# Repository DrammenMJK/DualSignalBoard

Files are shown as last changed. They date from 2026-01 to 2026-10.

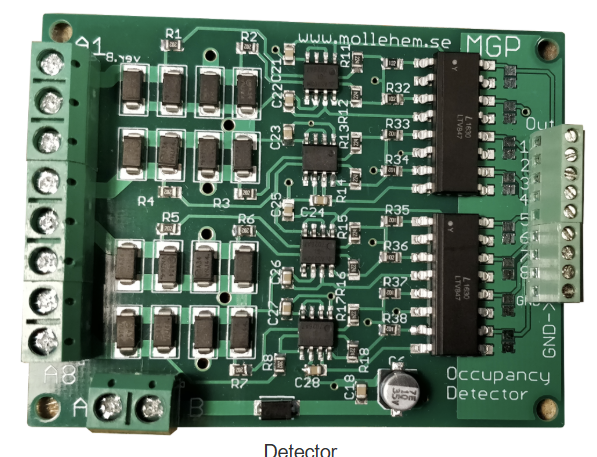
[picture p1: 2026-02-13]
MollhemSporavkanningDiodex8.png

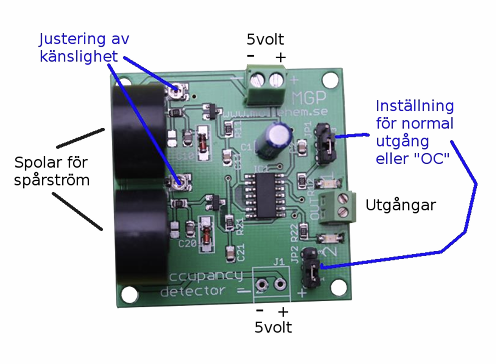
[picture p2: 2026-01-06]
MollehemSporavkanningx2.png

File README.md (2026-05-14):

# Railroad Signal Controller – Design Specification

## State Transitions and Signal Behavior

This section describes how the controller transitions between states based on
inputs and events.

---

### Direction State

**Direction** defines which end of the block is permitted to show green.

| Direction | Meaning |
|---|---|
| **A → B** | **Signal A** is the active green end |
| **B → A** | **Signal B** is the active green end |
| **None**  | **Signal A** and **Signal B** is both Red |

Direction **None** is the default state.

---

### Input Types

| Input | Trigger Type | Active State |
|---|---|---|
| PBA | **Edge-triggered** | LOW (press) |
| PBB | **Edge-triggered** | LOW (press) |
| SCA | **Level-based** | LOW (Closed) |
| SCB | **Level-based** | LOW (Closed) |
| SCC | **Level-based** | LOW (Closed) |
| Train | **Level-based** | HIGH (Train present) |

**Note:** The Train input is active HIGH (unlike other inputs which are active LOW). The train detection includes:
1. **IIR filter with hysteresis (20ms window)** - A leaky integrator filters the raw signal. Schmitt trigger thresholds prevent oscillation:
   - Goes HIGH when accumulator exceeds 60% (12ms)
   - Goes LOW when accumulator drops below 40% (8ms)
   - This ignores brief glitches and noisy signals like `0 1 0 1 0 1`
2. **2-second delay** - After the filtered signal goes HIGH, there is an additional 2-second delay before the signals are forced to red. If the filtered signal goes LOW before 2 seconds, the timer resets.

---

### Direction State Transitions

Direction changes **only on button press edges** and only when **no train is present**, and only if the  direction is not "None".

The possible directions are:

**A → B**
**B → A**
**None**

| Current Direction | Train present | Button event | Next Direction |
| --- | --- | --- | --- |
| None | No | **PBA pressed** | **A → B** |
| None | No | **PBB pressed** | **B → A** |
| Any | No | PBA or PBB pressed | No change |
| Any | Yes | PBA or PBB pressed| No change (stays None) |

Notes:

- PBA and PBB are evaluated on the **press edge only**
- Holding a button does **not** retrigger
- Pressing the button corresponding to the current Direction has no effect

Switches affects the direction signals

If any switch changes, then Direction is None thereafter. It does NOT change back.

---

### Signal Output Logic (Normal Operation)

| Condition | Signal A – Red | Signal A – Green 1 | Signal A – Green 2 | Signal B – Red | Signal B – Green 1 | Signal B – Green 2 |
|---|---|---|---|---|---|---|
| Direction **None** (or Train present) | ON | OFF | OFF | ON | OFF | OFF |
| Direction **A → B**, SCB open | ON | OFF | OFF | ON | OFF | OFF |
| Direction **A → B**, SCB closed, SCA open | OFF | ON | OFF | ON | OFF | OFF |
| Direction **A → B**, SCB closed, SCA closed | OFF | ON | ON | ON | OFF | OFF |
| Direction **B → A**, SCB open | ON | OFF | OFF | ON | OFF | OFF |
| Direction **B → A**, SCB closed, SCC or SCD open | ON | OFF | OFF | OFF | ON | OFF |
| Direction **B → A**, SCB closed, SCC closed, SCD closed | ON | OFF | OFF | OFF | ON | ON |

---

### Debug Mode State Transitions

| Current Debug Mode | Debug button pressed | Next Debug Mode |
|---|---|---|
| Off | Yes | AllOn |
| AllOn | Yes | Auto |
| Auto | Yes | Manual |
| Manual (step < last) | Yes | Manual (next step) |
| Manual (last step) | Yes | Off |

---

### Debug Cancellation

| Event | Effect |
|---|---|
| PBA or PBB pressed while in debug | Debug mode exits immediately |
| Debug cancelled | Direction does **not** change on same press |

---

### Power-On / Reset State

| Condition at Power-On | Resulting State |
|---|---|
| Debug button not held | Direction restored from EEPROM |
| Debug button held | Direction forced to **None**, EEPROM reset |

---

### Summary Rules

- Direction is **explicitly set**, never toggled
- PBA always selects **A → B**
- PBB always selects **B → A**
- Pushbuttons are **edge-triggered - high -> low**
- Switches and Train detection are **level-based**
- Train presence overrides all other logic
- Debug modes override lamp outputs but **do not modify Direction**
- EEPROM reset always restores a **known, safe Direction**

---

## Controller

- Board: **Arduino Uno–compatible (GeekCreit)**
- MCU: **ATmega328P**
- Clock: **16 MHz**
- EEPROM: **1 KB (on-chip)**

---

## Power

- System supply: **+10–12 V**
- Logic supply: **Buck regulator → 5.0–5.1 V**
- Arduino powered via **5V pin**
- VIN not used
- Grounds common for logic and outputs

---

## Inputs (All via Optocouplers)

- Optocoupler: **PC817 / EL817**
- Input voltage: **10–12 V**
- LED series resistor: **3.3 kΩ**
- Typical LED current: **~2–3 mA**
- Arduino side: `INPUT_PULLUP`
- Logic level: **LOW = active** (except Train input which is **HIGH = active**)

### Input Functions and Pins

| Function | Arduino Pin | Board Label |
|---|---|---|
| Train detect | D2 | 2 |
| Pushbutton A | D3 | 3 |
| Pushbutton B | D4 | 4 |
| Switch A closed | D5 | 5 |
| Switch B closed | A2 | A2 |
| Switch C closed | D6 | 6 |
| Switch D closed | A3 | A3 |
| Debug button | A4 | A4 |
| Serial enable jumper | A5 | A5 |

---

## Outputs (Discrete Transistor Drivers)

- Topology: **NPN low-side switching**
- Transistor: **BC547 / BC337 / 2N2222**
- Base resistor: **4.7 kΩ**
- Base pull-down: **100 kΩ (base → emitter)**
- Load: **Signal LEDs**
- LED supply: **+10 V**
- LED current: **10 mA**

### LED Series Resistor

- Nominal value: **680 Ω**
- Acceptable range: **680–820 Ω**
- Power rating: **¼ W**

### Output Functions and Pins

| Signal | Arduino Pin | Board Label |
|---|---|---|
| Signal A – Red | D7 | 7 |
| Signal A – Green 1 | D9 | 9 |
| Signal A – Green 2 | D8 | 8 |
| Signal B – Red | D10 | 10 |
| Signal B – Green 1 | D12 | 12 |
| Signal B – Green 2 | D11 | 11 |

- Logic: **Arduino HIGH = LED ON**
- Hardware inversion handled by transistor

---

## Debug LEDs (5 V Logic)

- Active-high
- Direct drive from Arduino pin
- Resistor: **1 kΩ**
- LED current: **~3 mA**

---

## Debug Button Behavior

- Button connected to **A4 → GND**
- `INPUT_PULLUP`
- Active-low

### Debug State Sequence

1. ALL_ON (=1) **All signal LEDs ON**
2. CYCLE (=2) **Automatic cycle** (1 s per LED):  
   A_G1 → A_G2 → A_R → B_G1 → B_G2 → B_R
3. MAN_0 (=3), MAN_1 (=4) ... MAN_5 (=8) **Manual step** (one press per LED, same order)
4. OFF (=0) (When enter state, Flash all 3 times, 0.5 sec between, then exit debug) **Exit debug → normal operation**

- Any press of **signal button A or B**:
  - Cancels debug immediately
  - Does **not** toggle signal state on same press

---

## Normal Signal Logic

- Default Direction is None
  Both signals are Red
- Startup state:
  - Direction None
- Train present (after 2-second delay):
  - Direction None
- Pushbutton A or B:
  - Sets direction only if Direction is None
  - Ignored if train present
- Switch A closed :
  - Both Greens for A on.  
- Switch B and C closed:
  - Both Greens for B is on.

- When a Train is present for 2 continuous seconds, both signals go Red.
- When train is no longer present, signals stay Red (direction remains None).

---

### Reset Mechanism

- Reset is performed using **power cycling**
- No dedicated reset jumper required

### Reset Steps

1. Power **OFF** the board using **JP2**
2. **Press and hold** the **Debug button (A4)**
3. Power **ON**
4. Release the Debug button after startup

### Reset Effect

- `g_stateQ` is forced to **false**
- Signal **A** becomes the active green end
- EEPROM address `0` is updated accordingly

---

## Serial Debug Output

- Baud rate: **115200**
- Status printed once per second
- Controlled by jumper on **A5**
  - Jumper installed (LOW): Serial enabled
  - Jumper removed (HIGH): Serial disabled

---

## Wiring Notes

- Input wire lengths: **2–5 m**
- Optocouplers required on all inputs
- Optional: **100 nF capacitor** across opto LED for noisy runs
- Avoid using pins **D0/D1**
- Pin **D13** unused (on-board LED available)

---

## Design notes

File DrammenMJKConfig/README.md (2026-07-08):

# DrammenMJKConfig

Console tool for configuring the LysKontroll Arduino controller over a serial connection.
Run it on a PC connected to the Arduino via USB. The program stores all configuration
in the Arduino's EEPROM and does not need to run during normal layout operation.

---

## Requirements

- .NET 8 runtime
- Arduino connected via USB (CH340 or genuine USB)
- Baud rate: 115200

---

## Starting the program

```txt
DrammenMJKConfig.exe
```

or

```txt
dotnet run
```

The program lists available COM ports. If only one is present it connects automatically;
otherwise you are prompted to choose. After connecting it waits 2 seconds for the Arduino
to finish its reset, then shows the main menu.

```txt
D = Debug mode    C = Config mode    V = Verify    Q = Quit
```

---

## Debug mode (D)

Used to check LED wiring before configuration.

| Key | Action |
|-----|---|
| A | Toggle all LEDs on / off — reveals short circuits |
| L | Cycle all LEDs one at a time, 1 second each (any key to stop) |
| Q | Exit debug mode |

---

## Config mode (C)

Stores hardware mappings in EEPROM. Run each command once during initial setup,
or again whenever the hardware changes.

**Recommended first-time order:** 1 → 2 → 3 → M → D → 4

### Command 1 — Motor scan

Discovers all switch motors in a single scan. Each motor pair is driven in turn:
- **Feedback changes** → Pens motor — operator confirms and sets Rett/Avvik polarity.
- **Timeout, no feedback change** → Dreieskive — operator confirms and sets CW/CCW polarity.

| Key | Action |
|-----|---|
| Y | Confirm / correct detection |
| N | Skip to next motor |
| R | Pens is currently at Rett position |
| A | Pens is currently at Avvik position |
| 1 | The `01` bit pattern drives CW (Dreieskive polarity) |
| 2 | The `10` bit pattern drives CW (Dreieskive polarity) |
| X | Emergency stop all motors |
| Q | Done, return to config menu |

### Command 2 — Manual switch → Pens mapping

Links each physical panel switch (B–I) to the corresponding Pens motor and feedback inputs.

1. Move **all** panel switches to Rett before starting.
2. Select a Pens letter (B–I).
3. Flip its panel switch to Avvik and back; the Arduino detects which input changed.
4. Confirm or retry, then set polarity.

| Key | Action |
|-----|---|
| B–I | Select a Pens to configure |
| Y | Confirm detected switch |
| N | Retry |
| R | Set polarity: this position is Rett |
| A | Set polarity: this position is Avvik |
| Q | Done |

### Command 3 — LED mapping

Maps each Pens (B–I) to its physical Rett and Avvik indicator LEDs on the panel.
All Penser should be at Rett before starting (run Command 2 first).

| Key | Action |
|-----|---|
| B–I | Select Pens to configure |
| N | Next LED |
| P | Previous LED |
| S | Save this LED for current switch position (Rett first, then Avvik) |
| Q | Done |

### Command M — Moment button

Detects which input pin the physical moment signal button is connected to.
Press the button when prompted. Confirm with Y or retry with N.

### Command D — Dreieskive switch

Configures the three-position turntable switch (middle / CW / CCW).

1. Move the switch to the **middle** position and press Enter.
2. Move to **CW** when prompted.
3. Move back to middle, then to **CCW**.
4. Confirm each step with Y.

### Command 4 — LED routing matrix

Controls which switch conditions must be satisfied before each indicator LED lights.
Configuration is loaded from a site-specific JSON file and uploaded to EEPROM.
See [RoutingMatrix.md](RoutingMatrix.md) for the file format and a complete Fossli example.

```
Routing> L   Load JSON file and upload to Arduino
Routing> S   Download current matrix from Arduino and save to JSON file
Routing> ?   Show JSON file format and example
Routing> Q   Done
```

When loading, the program:
1. Prompts for the path to a `.json` file (any name, one per site).
2. Displays the `site` label from the file so you can confirm it is the right one.
3. Validates all conditions and reports every error before asking to upload.
4. Sends the matrix to Arduino and confirms each LED row is accepted.

### Command R — Reset

**Destructive.** Erases all configuration from EEPROM (motor mappings, switch mappings,
LED mappings, polarity, routing matrix). The layout signal direction state is not affected.
Requires typing Y to confirm.

After a reset, run Commands 1, 2, 3, M, D and 4 to reconfigure.

---

## Verify mode (V)

Checks that the hardware still works correctly using the stored configuration.
Nothing is written to EEPROM.

### Command 1 — Motors and Pens feedback

For each configured Pens the Arduino:
1. Reads current position from feedback switches.
2. Moves the motor to the opposite position and confirms feedback changes.
3. Moves back and confirms again.
4. Reports PASS or FAIL.

The Dreieskive motor is skipped (no feedback switches).

| Key | Action |
|-----|---|
| X | Emergency stop all motors |
| Q | Abort and return to verify menu |

---

## Site-specific files

The LED routing matrix is the only configuration stored outside the Arduino.
Keep one JSON file per physical layout:

| Site | File |
|---|---|
| Fossli | `Fossli.json` |
| Other site | `Sentrum.json`, etc. |

Pass the full path when prompted by Command 4 → L. The file may be stored anywhere.
See [RoutingMatrix.md](RoutingMatrix.md) for the format specification.

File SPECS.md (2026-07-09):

# LysKontroll — System Specification

Model railway layout controller for Drammen MJK, station Fossli.
Hardware: Arduino Uno (ATmega328P). Software: Arduino firmware + C# config tool.

---

## Hardware

| Component | Description |
|---|---|
| ATmega328P | 32 KB flash, 2 KB SRAM, 1 KB EEPROM (100 K write cycles) |
| MCP23017 | I2C GPIO expanders for additional I/O |
| Pens motors | Turnout motors, stall-hold (`01` or `10`), never `00` |
| Feedback switches | Two per Pens (Rett + Avvik pin), read via I2C |
| Manual switches | One per Pens (operator panel), read via I2C |
| Dreieskive motor | Rotating platform, 3 states: `00`=stopped, CW, CCW |
| Dreieskive switch | 3-position panel switch: middle / CW / CCW |
| LEDs | Rett + Avvik indicator per Pens, driven via I2C |
| Moment button | Physical signal-operation button |

---

## Site Configuration

Stored in EEPROM and in the site JSON file. Change per site without recompiling
(simulator uses `#define`; real firmware reads from EEPROM after initial upload).

| Parameter | Default | Fossli |
|---|---|---|
| `FIRST_PENS` | `'A'` | `'B'` |
| `LAST_PENS` | site-specific | `'I'` |
| `MAX_PENS` | 26 (A–Z) | 26 |
| `NUM_LED_OUTPUTS` | site-specific | 16 |

`LED_COUNT` (number of logical LED slots in the routing matrix) is derived: `(LAST_PENS - FIRST_PENS + 1) * 2`. It is **not** a site config — it follows automatically from the Pens range. `NUM_LED_OUTPUTS` is the number of physical hardware LED driver outputs and must be set per site.

---

## EEPROM Layout (1 024 bytes, ATmega328P)

All slots initialised to `0xFF`. `0xFF` in any slot = not yet configured.
Regions are indexed from `FIRST_PENS` (index 0 = `FIRST_PENS`, 1 = next letter, …).

| Address | Size | Content |
|---|---|---|
| `0x01` | 1 | Magic byte (`0xA5` = EEPROM has been initialised) |
| `0x0A` | 1 | Dreieskive last known position (display hint only) |
| `0x10` (REGION1_BASE) | MAX_PENS | Motor pair index per Pens |
| `0x30` (REGION1_POL) | MAX_PENS | Motor polarity (position at scan time: 0=Rett, 1=Avvik) |
| `0x50` (REGION2_RETT) | MAX_PENS | Feedback Rett pin per Pens |
| `0x70` (REGION2_AVVIK) | MAX_PENS | Feedback Avvik pin per Pens |
| `0x90` (REGION3_BASE) | MAX_PENS | Manual switch pin per Pens |
| `0xB0` (REGION4_RETT) | MAX_PENS | Rett LED index per Pens (`0xFF`=not set, `0xFE`=no LED, `0x00–0x0F`=index) |
| `0xD0` (REGION4_AVVIK) | MAX_PENS | Avvik LED index per Pens (same encoding) |
| `0xF0` (REGION5_MOTOR_PIN) | 1 | Dreieskive motor pair index |
| `0xF1` (REGION5_MOTOR_POL) | 1 | Dreieskive CW polarity (0=`01`, 1=`10`) |
| `0xF2` (REGION5_SW_CW) | 1 | Dreieskive switch CW pin |
| `0xF3` (REGION5_SW_CCW) | 1 | Dreieskive switch CCW pin |
| `0xF4` (REGION5_MOMENT) | 1 | Moment button pin |
| `0x100` (REGION6_BASE) | 144 | LED routing matrix (16 LEDs × 9 bytes) |

Pens positions are NOT stored in EEPROM — kept in RAM, refreshed from I2C feedback
on every loop iteration. EEPROM write cycles are preserved.

---

## Serial Protocol

Baud rate: **115 200**.

### C# → Arduino
- Single ASCII characters (no newline) for interactive commands and key presses.
- Full lines ending `\n` only during routing matrix upload.

### Arduino → C#
- Lines ending `\r\n`.
- **`!` prefix** — status message: always displayed immediately, `!` stripped.
- **No prefix** — protocol response (`READY`, `OK`, `STORED`, `END`, `ERR`):
  queued in capture mode, or displayed with `[A]` prefix in relay mode.

### C# ReadLoop (background thread)
```
line starts with '!'  →  Console.WriteLine(line without '!')
capturing             →  enqueue for caller (GetCapturedLine)
otherwise             →  Console.WriteLine("[A] " + line)
```

### Capture mode
Used for structured exchanges (routing matrix upload/download).
`StartCapture()` redirects non-`!` lines to a queue.
`StopCapture()` resumes normal relay behaviour.

---

## C# Program Structure

```
Program.cs          — port selection, startup, main menu (C / D / V / Q)
ArduinoConnection   — serial port + ReadLoop thread
ConfigSession       — config mode commands
DebugSession        — debug mode
VerifySession       — verify mode
```

After connecting, `Program.cs` waits 2 s then sends `'S'` and waits 400 ms
to let the Arduino return EEPROM status before showing the main menu.

---

## Relay Mode

`Relay()` in `ConfigSession` forwards every keystroke to the Arduino and
displays `!` status lines. C# has no command knowledge in relay mode — the
Arduino drives the entire interaction.

- **ESC** — breaks `Relay()` on the C# side AND is sent to the Arduino so
  the current command can also abort. Both sides exit simultaneously.
- Commands that complete **naturally** (not via ESC) must call
  `while (waitKey() != ESC) {}` before returning, so `Relay()` also exits.

---

## Key Bindings

### Main menu (`Program.cs`)
| Key | Action |
|-----|---|
| C | Config mode |
| D | Debug mode |
| V | Verify mode |
| Q | Quit (sends Q to Arduino for reset, then C# exits) |

### Config menu (Arduino `runConfig`, C# `ConfigSession`)
| Key | Action |
|-----|---|
| 1 | Motor scan |
| 2 | Switch mapping |
| 3 | LED mapping |
| 4 | Routing matrix |
| M | Moment button |
| D | Dreieskive switch |
| R | Reset EEPROM |
| Q | Exit config mode |

### Motor scan (relay mode)
| Key | Action |
|-----|---|
| `FIRST_PENS`–`LAST_PENS` | Identify which Pens just moved |
| `0` | Skip this pair |
| `R` / `A` | Pens is now at Rett / Avvik |
| `1` / `2` | Dreieskive CW = `01` / `10` pattern |
| `X` | Emergency stop |
| `Y` / `N` | Override duplicate / re-enter letter |
| Esc | Abort scan |

### Switch mapping (relay mode)
| Key | Action |
|-----|---|
| `FIRST_PENS`–`LAST_PENS` | Map or re-map that Pens switch |
| Esc | Finish |

### LED mapping (relay mode)
| Key | Action |
|-----|---|
| `FIRST_PENS`–`LAST_PENS` | Select Pens to configure (or re-configure) |
| `N` / `P` | Next / previous LED index (wraps) |
| `S` | Save current LED for this position (Rett first, then Avvik) |
| `0` | No physical LED for this position (stores `LED_NO_PIN = 0xFE`) |
| Esc | Finish |

### Routing matrix (structured protocol, not relay)
| Key | Action |
|-----|---|
| `U` | Upload from C# JSON file |
| `D` | Download to C# JSON file |
| `?` | Show JSON format |
| Esc | Done |

---

## Motor Scan Flow

1. Pre-populate `assigned[]` and `pairDone[]` from EEPROM.
2. If **all** Pens and Dreieskive are already configured:
   - Prompt "Type a Pens letter to re-configure it, or Esc to finish."
   - Operator types a letter (e.g. `C`): clears that one Pens from session state and clears its pair from `pairDone[]`.
   - Falls through to the pair scan — only the cleared pair will run; all others skip.
   - After the pair is re-assigned, loops back to step 2 to offer editing another.
   - `Esc` at this prompt → "Motor scan done." and returns.
3. Loop pairs `0..8`:
   - `pairDone[pair]` → silent skip.
   - All Pens already assigned → silent skip (only Dreieskive pair can still fire).
   - **Dreieskive pair** (no feedback timeout): automatically identified — ask `1`/`2` for CW polarity.
   - **Pens pair** (feedback detected): show remaining unassigned letters, operator types letter.
     - Duplicate detected → `Y` override / `N` re-enter.
     - Ask current position `R`/`A`, store to EEPROM.
4. Early exit when all Pens **and** Dreieskive are done.
5. `"Motor scan complete. Press Esc to return."` — waits for Esc.

---

## Switch Mapping Flow

Loop: operator types any Pens letter to map or re-map it, Esc to finish.
1. Check motor configured for that Pens (REGION1_BASE); error if not.
2. Drive that Pens to Rett (so switch follows).
3. Prompt operator to flip the panel switch to Avvik then back to Rett.
4. Detect switch (2 s), store pin to EEPROM, confirm stored.

No Y/N confirmation needed — the operator typed the letter intentionally.
Already-mapped Pens are silently re-mapped when the letter is typed again.

---

## LED Routing Matrix

- 16 logical LEDs: `B_Rett`, `B_Avvik`, `C_Rett`, `C_Avvik` … `I_Rett`, `I_Avvik`.
- Each LED holds up to 4 conditions (OR of AND-chains).
- Each condition: `rettMask` + `avvikMask` (bitmask of Pens that must be in that position).
- `count = 0xFF` → default 1-to-1 (LED lights when its own Pens is in matching position).
- `count = 0x00` → suppressed (always off; used for shared physical LEDs).
- Loaded from a site-specific JSON file (e.g. `Fossli.json`).

Wire format per LED: `CC [RR AA …]` (hex, space-separated).

---

## Simulator (`Simulator.ino`)

Replaces real hardware for testing the C# config program on an empty Arduino Uno.

- All strings in flash via `F()` and `vsnprintf_P`. No `String` objects.
- `#define ESC '\x1B'` — abort/quit inside all commands.
- `Q` reserved for top-level menus only (`runConfig`, `loop`).
- `'S'` command (silent) — returns EEPROM status; sent by C# after connect.
- `softReset()` — watchdog reset; **does not clear EEPROM**.
- `SIM_DREIESKIVE_PAIR = 4` — pair with no feedback (simulated Dreieskive).
- `SIM_PENS_COUNT = 8` — Fossli has 8 Pens (B–I).
- EEPROM indexing: `eepromIdx = k - FIRST_PENS` (site-relative, 0 = first Pens).
- In-session arrays (`assigned[]`, `simPensPos[]`): indexed by `k - 'A'` (universal, 0 = A).

---

## Key Design Rules

**Y, N, and all A–Z letters are reserved as Pens identifiers.**
They must NEVER be used as yes/no confirmation keys inside any command that
also accepts Pens letter input. Since FIRST_PENS/LAST_PENS may expand to cover
the full A–Z range on other sites, any A–Z letter is off-limits as a confirmation
key in relay mode.

Safe confirmation/action keys (outside A–Z or not reachable from Pens letter range):
- Digits: `0`–`9`
- Esc (`\x1B`)
- `1` / `2` (Dreieskive polarity choice)

Y/N are only permitted in pure C# dialogs that never reach the Arduino in relay mode
(e.g. "Upload to Arduino? Y/N" in `LoadAndUpload`), or in Arduino commands that do
not accept Pens letters at all (moment button, Dreieskive switch) — and only then on
sites where Y/N are outside FIRST_PENS..LAST_PENS.

**Prompts must appear before blocking on input.**
The Arduino must send its status prompt BEFORE calling `waitKey()`, so the user
sees what to type without needing to press a dummy key first. Invalid keys are
silently ignored (loop repeats the prompt).

---

## Conventions

| Term | Meaning |
|---|---|
| Rett | Straight-through position (value 0) |
| Avvik | Diverging position (value 1) |
| Pens | Physical turnout / switch (Norwegian: veksel) |
| Dreieskive | Rotating platform (turntable) |
| eepromIdx | `k - FIRST_PENS` — EEPROM array offset for Pens letter `k` |
| pensIdx | `k - 'A'` — universal in-memory index for Pens letter `k` |

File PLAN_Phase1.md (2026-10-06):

# Plan: Phase 1 Implementation (FSCB over direct I2C)

Implements the Phase 1 scope defined in `PlanExtended.md`. This document is the
concrete build plan: code layering, protocol, EEPROM layout and task order.

## Relationship to other docs

- `PlanExtended.md` is the source of truth for scope and hardware facts. This
  file only turns it into an implementation plan.
- `PlanExtended.md` describes a **new, bigger architecture** (SVB + SCB boards,
  numbered switches, 4 I2C buses via a mux) that supersedes the older
  letter-based Penser (A–Z) extension of the original DualSignal lamp
  controller described in `SPECS.md` / `PLAN_PensControl.md` / `PLAN_Refactor.md`.
- `Firmware_FirstAttempt/Firmware.ino` is an implementation of that **older**
  Pens-letter system (`MF`/`MS`/`FW`/`SW`/`SCA`, EEPROM Region1–6, Pens A–Z).
  Per `PlanExtended.md`: "we will not reuse this". It's still useful as a
  reference for MCP23017 driver code style and pin-encoding tricks, but the
  command protocol and EEPROM layout below are new and unrelated to Region1–6.
- `Simulator/Simulator.ino` is the copy source for `Firmware/`. We keep its
  **transport plumbing** (line reader, capture-mode-safe response format,
  `!`-prefixed status lines) and its **EEPROM primitive commands**
  (`PING`/`SI`/`ER`/`EW`/`EC`/`RST`), and discard the simulated-Pens business
  logic entirely.

## Guiding architectural decision (revised)

`PLAN_Refactor.md`'s "config logic lives in C#" rule applies to
**config-time, interactive** logic — scan loops, operator prompts, "which one
moved?" bookkeeping. It does **not** mean the PC is the runtime brain: in
production there is no PC attached. The Arduino (CB) must be able to power up
and run the layout entirely on its own, driven by:

- its own downloaded EEPROM config (built once, during config sessions), and
- hardware events on the buses — an SVB's panel switch changing state, later
  (Phase 2+) triggering the corresponding SCB motor, all inside the firmware.

So the split is:

| Lives in C# (`DrammenMJKConfig`) | Lives in firmware (`Firmware.ino`) |
|---|---|
| Editing `hardware.json` (board types × site board inventory) and `SystemConfig.json` | Applying the uploaded board hardware table (IODIR/GPPU per board) at boot and live on upload |
| Interactive discovery UX: motor scan prompts, "which switch moved?", Rett/Avvik confirmation | The switch table itself (slot → board + motor bit + polarity + feedback bits), read at runtime |
| Human-friendly naming: SVB name/number ↔ switch number ↔ switch slot | Resolving "drive switch N" / "read switch N" from that table, without needing a PC |
| Building/uploading both tables during config | — |
| — | (Later) reacting autonomously to SVB switch-change events, same table, same resolver |
| — | (Later) signal-lamp PWM/dimming logic, native firmware, not decomposed to C# — see [Signal lamp logic](#signal-lamp-logic-out-of-scope) |

Practically, this means the wire protocol has two tiers:

- **Raw discovery primitives** (`MDIR`/`MPU`/`MW`/`MR`/`MPOLL`/`MBIT`) — take
  an explicit `(vaddr, port, bit)` because during Motor Scan that mapping is
  exactly what's *unknown* and being discovered. These are config-time-only.
- **Switch-level commands** (`SW`/`SR`, new) — take only a switch **slot**
  number. No port, no bit, no vaddr. The firmware looks those up itself from
  the switch table already written into EEPROM by Motor Scan. This is what
  Command mode uses, and it's the same lookup the future autonomous runtime
  loop will use — so Command mode is effectively "manually trigger the same
  resolver the SVB-event loop will call later," not a separate code path.

---

## Virtual addressing

`PlanExtended.md`'s "System description" section gives the site's full address
map and states the formula as "Bus number * 20 + local address". The worked
table underneath it is the authoritative data, and it's consistent with a
multiplier of **`0x10`**, not `0x20`:

| Bus | Boards | Real address(es) | Virtual address(es) |
|---|---|---|---|
| 0 — Stillverk | SVB1 LedAndSwitchesFossli, SVB2 LedAndSwitchesHavna | `0x20`,`0x21`,`0x22`,`0x23` | same (`0x20`–`0x23`) |
| 1 — Havna/Vallekilen | Havna SCB, Vallekilen SCB, Vallekilen SVB | `0x20`,`0x21`,`0x22` | `0x30`,`0x31`,`0x32`,`0x33` |
| 2 — Fossli | Fossli Høyre (FSCB), Fossli Venstre | `0x20`,`0x21` | `0x40`,`0x41` |
| 3 — Sidespor | Sidespor | `0x20` | `0x50` |

(Vallekilen is two virtual addresses, `0x32` SCB + `0x33` SVB — not a single
combined board as an earlier draft of `PlanExtended.md` implied.)

Each real address diffs from its virtual address by exactly `bus * 0x10`
(Bus1: `+0x10`, Bus2: `+0x20`, Bus3: `+0x30`). So:

```
virtual_address = bus_number * 0x10 + real_i2c_address        // real_i2c_address is always 0x20–0x27 (MCP23017)

// decode (inverse), given real addresses are always in 0x20–0x2F:
bus_number      = (virtual_address >> 4) - 2
real_i2c_address = 0x20 | (virtual_address & 0x0F)
```

This holds for every entry in the table above, including Bus 0 where the
"virtual == real" statement falls out of the formula for free (`bus=0` adds
nothing). It also holds for FSCB itself: Phase 1's direct-wired address
`0x20` **is already a valid virtual address** for `bus=0` — so Phase 1 doesn't
need a special case, it's just the `bus=0` instance of the same scheme, and
the value doesn't change when FSCB is later moved to Bus 2 (`0x40`) — only the
`BoardConfig` entry's virtual address constant changes.

Bus handling lives in the firmware's I2C layer, and only there: the raw
discovery commands and the switch table both carry `vaddr`, never `bus`. The
resolver decodes `bus`/`real_addr` from `vaddr` and selects the mux channel
before issuing the transaction. Dispatch code never mentions `bus`.

**No board-discovery/scan command exists or is wanted.** Every board's
virtual address is a known, fixed constant from the site map above — it's
data in `BoardConfig`, not something firmware or the PC probes for. A board
that doesn't answer on its known address means its I2C link is broken or it
isn't wired in yet, not "not found".

---

## Firmware layering (`Firmware/Firmware.ino`)

```
┌──────────────────────────────────────────────────────────────────┐
│ 1. Serial transport (PSL)                                        │
│    readLine(), dispatch(), OK/ERR/status(!) conventions          │
│    — copied from Simulator.ino, simulation stripped              │
├──────────────────────────────────────────────────────────────────┤
│ 2. Command dispatch                                               │
│    PING / SI / ER / EW / EC / RST        (local, unchanged)       │
│    MDIR / MPU / MW / MR / MPOLL / MBIT   (raw, discovery-only)    │
│    SW / SR                                (switch-table, operational)│
│    HWU / HWD                              (board hw table, bulk) │
│    SCU / SCD                    (switch/SVB-switch/dreieskive/LED, bulk)│
├──────────────────────────────────────────────────────────────────┤
│ 3a. Board hardware table (EEPROM-backed — see EEPROM layout)      │
│    resolve_board_hw(vaddr) -> {iodirA, iodirB, gppuA, gppuB}      │
│    or NOT_CONFIGURED. Applied to every registered vaddr at boot,  │
│    and immediately (live) whenever HWU stores a new table.        │
│ 3b. Switch table (EEPROM-backed, generic schema)                  │
│    resolve_switch(slot) -> {motorVAddr, motorBit, polarity,       │
│      feedbackVAddr, fbRettBit, fbAvvikBit}  or NOT_CONFIGURED     │
│    motor/feedback vaddr independent — a 2-chip board's feedback   │
│    can land on the other chip from its motor.                     │
│    Used by SW/SR now; will be used by the autonomous SVB-event    │
│    loop later (Phase 2+) — same function, no protocol change.     │
├──────────────────────────────────────────────────────────────────┤
│ 4. Virtual-address resolver (bus lives here, and only there)      │
│    resolve_vaddr(vaddr) -> { bus, real_addr }                     │
│      bus       = (vaddr >> 4) - 2                                  │
│      real_addr = 0x20 | (vaddr & 0x0F)                             │
│    i2c_select_bus(bus)                                             │
│    Phase 1: bus is always 0 -> select is a no-op                  │
│              (no mux fitted; single direct bus)                    │
│    Phase 2+: drives the I2C mux channel select                      │
├──────────────────────────────────────────────────────────────────┤
│ 5. Generic MCP23017 driver                                        │
│    mcp_write_reg / mcp_read_reg / mcp_set_dir / mcp_set_pu        │
│    Same 3 primitives as PLAN_Refactor.md's "custom driver"        │
│    Reused unchanged by every future board type.                    │
└──────────────────────────────────────────────────────────────────┘
```

There is now **no compiled-in board-specific code at all**, not even the SCB
port template — layers 3a/3b are both generic table interpreters over
EEPROM data. That's an improvement on the previous draft, which still
hardcoded FSCB's port setup directly in firmware C++ (recompile+reflash
needed for any port-role change). Now it's a small uploaded table, exactly
the same shape/spirit as the switch table.

### `hardware.json` and the board hardware table

Corrected from an earlier whole-port draft: MCP23017's `IODIR`/`GPPU`
registers are genuinely per-bit, and `PlanExtended.md`'s "Hardware
configuration" section confirms boards actually mix input and output *within*
one port — an SVB's LED-output port can have one bit repurposed as a motor
output on the Vallekilen combined board, for instance. A whole-port
`{direction, pullup}` can't express that, so each port is an **8-element
array**, index 0 = bit 0 .. index 7 = bit 7, each element one of:

- `"out"` — output
- `"in"` — input, no pull-up
- `"in-pu"` — input, internal pull-up enabled

No shared type templates — an earlier draft had a `boardTypes` indirection
("SCB" boards all inherit one port layout), which turns out not to fit this
system: `PlanExtended.md`'s site map has 5 SCBs and 3 SVBs, and each one has
*its own* input/output configuration — there's no common template to actually
share, so the indirection was pure overhead with nothing behind it. Every
board just declares its own ports directly.

`boards` is a plain **array**, one entry per physical board, matching
`PlanExtended.md`'s site map. Each board has a `category` (`SCB` / `SVB` /
`Combined`, per the doc's "one combined stillverk and switch control board")
and a `chips` array — **1 or 2 MCP23017 entries**, each with its own `vaddr`
and its own two 8-element port arrays (index 0 = bit 0 .. index 7 = bit 7):

- `"out"` — output
- `"in"` — input, no pull-up
- `"in-pu"` — input, internal pull-up enabled

```json
{
  "boards": [
    {
      "name": "Fossli Høyre (FCSBR)",
      "category": "SCB",
      "chips": [
        {
          "vaddr": "0x20",
          "portA": ["in-pu", "in-pu", "in-pu", "in-pu", "in-pu", "in-pu", "in-pu", "in-pu"],
          "portB": ["out",   "out",   "out",   "out",   "out",   "out",   "out",   "out"]
        }
      ]
    }
  ]
}
```

(Renamed from FSCB to `FCSBR` — `PlanExtended.md` now distinguishes "Fossli
Switch Control Right Side Board" from a left-side counterpart; see below.)

Port A bits 0–7 all `in-pu` (the four feedback pairs), Port B bits 0–7 all
`out` (0–3 motors, 4–5 dreieskive, 6 spare, 7 status LED) — matches FCSBR's
spec exactly, and happens to be uniform per port for this one board. A
2-chip board (e.g. SVB1 `LedAndSwitchesFossli` at `0x20` **and** `0x21`) is
just a `chips` array with two entries instead of one — same board, two
independent port configurations, since each MCP23017 is wired however it's
wired:

```json
{
  "name": "LedAndSwitchesFossli",
  "category": "SVB",
  "chips": [
    { "vaddr": "0x20", "portA": [ /* … */ ], "portB": [ /* … */ ] },
    { "vaddr": "0x21", "portA": [ /* … */ ], "portB": [ /* … */ ] }
  ]
}
```

**Fourth enum value, `"tbd"`**: exists for exactly the situation `PlanExtended.md`'s
newly added FCSBL board (Fossli left side, `0x21`) was in briefly — its I/O
*counts* were known (3 switch motors, 3 signal LEDs, 1 status LED, 6 feedback
bits, 1 track-detect bit — 14 of 16 bits, so it fits one chip) before its
exact bit *positions* were. `"tbd"` joins `"out"`/`"in"`/`"in-pu"` as a fourth
legal per-bit value meaning "not yet determined", and `HardwareConfigUpload`
must refuse to include any chip with a `"tbd"` entry in an `HWU` upload — so
a placeholder file can never reach real hardware while it's still incomplete.
FCSBL's own layout is fully known now (its "Port B config Left"/"Port A
config Left" spec), so its actual `hardware.json` entry doesn't use `"tbd"`
any more — but the mechanism stays, for the next board that starts out
partially specified:

```json
{
  "name": "Fossli Venstre (FCSBL)",
  "category": "SCB",
  "chips": [
    {
      "vaddr": "0x21",
      "portA": ["in-pu", "in-pu", "in-pu", "in-pu", "in-pu", "in-pu", "in-pu", "in-pu"],
      "portB": ["out",   "out",   "out",   "out",   "out",   "out",   "out",   "out"]
    }
  ]
}
```

Converted from `PlanExtended.md`'s literal wording, which mixes two
numbering bases across the two ports — Port B given 1-based (pins 1–8), Port
A given 0-based (pins 0–5, 7) — self-disambiguating since a 0-based range
can't contain "8" and a 1-based range can't contain "0". Port B pin *N* → bit
*N−1*: bits 0–2 = the 3 real switch motors, bits 4–6 = the 3 signal LEDs
(Red/Green1/Green2, order still unknown), bit 7 = the connectivity warning
LED. Port A pins used as-is: bits 0–5 = 3 feedback pairs (0-1/2-3/4-5,
matching FCSBR's pairing convention), bit 7 = track detection.

Of the 16 bits, 15 are actually connected to something and 1 (Port A bit 6)
is not connected at all. Of those 15, 14 are the functionally meaningful
ones just listed; the 15th (Port B bit 3) **is** wired — to the motor driver
output stage, same as bits 0–2 — but has no switch attached to it, so it's
connected yet functionally idle. Both spares still get a direction in
`hardware.json` (`"out"` for bit 3, since it's genuinely wired as a motor
output; `"in-pu"` for Port A bit 6, to avoid leaving a truly floating input)
even though neither has a `SystemConfig.json` entry.

Direction is now fully resolved for both boards, and turns out identical —
Port A all `in-pu`, Port B all `out` — even though `PlanExtended.md` warned
pin *assignments* would differ per board ("commonality: all SCBs will have
similar setup, but the pin assignments will differ"). That statement held:
which specific bit does what differs completely between FCSBR and FCSBL: only
the port-level direction pattern happens to coincide.

Actual file: `DrammenMJKConfig/hardware.json` — also carries a top-level
`"_todo"` array (see [System configuration persistence](#system-configuration-persistence-systemconfigjson)
for the same convention applied to `SystemConfig.json`) recording what's
still open: the numbering-base conversion above hasn't been independently
verified against a schematic, and how FCSBL's signal-lamp dimming is actually
achieved given MCP23017 GPIO has no native PWM.

`category` isn't used by firmware at all (it never sees `hardware.json`, only
the flat resolved register table) — it's for C#, so logic like "which boards
are eligible targets for Motor Scan" (`SCB` and `Combined`, never plain
`SVB`) or "which board carries this SVB's operator panel + indicator LEDs"
doesn't have to guess from port layout.

The mixed-port exception `PlanExtended.md`'s "Switch drivers" section already
flags for plain SCBs ("in some cases we have to use parts of Port A also for
output") needs nothing special either — it's just a chip whose `portA` array
has an `"out"` mixed in among the `"in-pu"` entries. Nothing about the schema
distinguishes "the common case" from "the exception" anymore, since there
turned out not to be a common case.

C# flattens every board's every chip into one resolved row
(`vaddr, iodirA, iodirB, gppuA, gppuB` — plain register bytes, one bit per
array element: `"out"` → IODIR bit `0`, `"in"`/`"in-pu"` → IODIR bit `1`,
`"in-pu"` → GPPU bit `1` else `0`) before uploading via `HWU` — one line per
chip, regardless of which board it belongs to or how many chips that board
has. Firmware never parses JSON, never sees `category`, `name`, or the
board/chip nesting; it only ever sees the flat resolved table.

Not scanned or discovered — unlike the switch table, this is **declared**,
straight from known site facts (per [Virtual addressing](#virtual-addressing),
no board-discovery happens anywhere in this system). Uploading it is a
prerequisite for Motor Scan, not a product of it: Motor Scan assumes Port B is
already output and Port A is already input+pullup on the board it's scanning.

**What this file deliberately does *not* say**: `PlanExtended.md`'s new
section also lists *purposes* per bit (motors, on-board LED, dimmed track
signal LEDs, switch feedback, toggle/moment switches, track detection for
SCBs; position LEDs, an occasional motor, signal indication, on/off and
3-position toggles, moment button for SVBs). None of that belongs in
`hardware.json` — direction/pull-up is a fixed electrical fact of the board
design, but *which specific bit drives which specific switch/LED/signal* is
a per-site wiring fact, discovered by Motor Scan (or its future LED/switch/
signal counterparts) and stored in `SystemConfig.json`. `hardware.json`
answers "is this pin an input or output"; `SystemConfig.json` answers "what
is this specific pin actually connected to here". Keeping purpose out of
`hardware.json` is what keeps the boot-time bring-up routine fully generic —
it only ever needs direction and pull-up, never purpose.

### Boot-time hardware bring-up (data-driven — replaces the earlier "C# does it" design)

Turning off FSCB's "no comms" red LED (GPB7) was previously sketched as a C#
startup step. That's wrong for the same reason as everything else here: it
must work with no PC attached. It's firmware's `setup()`, driven entirely by
the board hardware table uploaded via `HWU`:

```
for each configured entry in the board hardware table (BoardVAddr[i] != 0xFF):
    MDIR(BoardVAddr[i], PORT_A, BoardIodirA[i])
    MDIR(BoardVAddr[i], PORT_B, BoardIodirB[i])
    MPU (BoardVAddr[i], PORT_A, BoardGppuA[i])
    MPU (BoardVAddr[i], PORT_B, BoardGppuB[i])
    MW  (BoardVAddr[i], PORT_A, 0x00)   // universal safe default: LEDs/inputs
    MW  (BoardVAddr[i], PORT_B, 0x00)   // off, motors arbitrary-but-valid direction
                                         // (safe for FSCB's one-pin-per-motor design —
                                         // see PLAN_PensControl.md for why a two-pin
                                         // H-bridge board would need a different default)
```

The same routine runs immediately after `HWU` finishes storing (so a freshly
uploaded table takes effect without a reboot), and once at boot. On a
completely fresh Arduino (board hardware table never uploaded), boot does
nothing to any board — ports stay at the MCP23017's own power-on default
(everything an input) until `hardware.json` is uploaded once. That's a safer
default than the earlier hardcoded-template version, which assumed FSCB's
specific setup unconditionally.

### Firmware protocol

All addresses/values as 2-digit uppercase hex, same convention as the
existing `ER`/`EW` commands. `port` is `A` or `B`. `vaddr` is the virtual
address byte (see [Virtual addressing](#virtual-addressing)). `slot` is a
switch-table index (see [EEPROM layout](#eeprom-layout)).

**Raw discovery primitives** — used only by Motor Scan, where the mapping is
still unknown, and for bench debugging:

| Command | Params | Response | Meaning |
|---|---|---|---|
| `MDIR` | `<vaddr> <port> <mask>` | `OK` / `ERR` | Set IODIR (bit=1 input, 0 output) |
| `MPU`  | `<vaddr> <port> <mask>` | `OK` / `ERR` | Set GPPU pull-ups |
| `MW` | `<vaddr> <port> <val>`  | `OK` / `ERR` | Write OLAT (drive outputs) |
| `MR` | `<vaddr> <port>` | `<hex byte>` / `ERR` | Read GPIO register |
| `MPOLL`| `<vaddr> <port> <baseline> <timeoutMs>` | `CHANGED <hex>` / `TIMEOUT` | Block locally, polling every ~5 ms, until the port value differs from `baseline` or the timeout elapses |
| `MBIT` | `<vaddr> <port> <bit> <val>` | `OK` / `ERR` | Read-modify-write a single OLAT bit (used during scan to fire one motor without disturbing others already found) |

**Switch-table commands** — used by Command mode, and later by the autonomous
runtime loop internally (no wire protocol involved at that point, just the
same internal `resolve_switch()` call):

| Command | Params | Response | Meaning |
|---|---|---|---|
| `SW` | `<slot> <R\|A> <timeoutMs>` | `OK <RETT\|AVVIK\|BETWEEN>` / `TIMEOUT` / `ERR unconfigured` | Look up `slot`, drive its motor bit to the polarity-adjusted level for the requested position, then block polling its feedback pair (like `MPOLL`, internally) until it settles or times out |
| `SR` | `<slot>` | `RETT` / `AVVIK` / `BETWEEN` / `FAULT` / `ERR unconfigured` | Look up `slot`, read its feedback pair, decode via stored polarity |

**Board hardware bulk transfer** — `hardware.json` upload/download (see
[hardware.json and the board hardware table](#hardwarejson-and-the-board-hardware-table)).
Uploading also (re)applies the table live, not just at next boot:

| Command | Params | Response | Meaning |
|---|---|---|---|
| `HWU` | — | `READY`, then per line `OK`/`ERR`, then `STORED` after `END`; then immediately applies every entry (as at boot) | Upload: C# sends one line per board, `END` to finish |
| `HWD` | — | one line per **configured** board, then `END` | Download: dump every board with `BoardVAddr != 0xFF` |

Line format: `<vaddr> <iodirAHex> <iodirBHex> <gppuAHex> <gppuBHex>`.

**System-config bulk transfer** — `SystemConfig.json` backup/restore (see
[System configuration persistence](#system-configuration-persistence-systemconfigjson)),
structured line protocol identical in shape to the existing
`RMU`/`RMD` routing-matrix commands:

| Command | Params | Response | Meaning |
|---|---|---|---|
| `SCU` | — | `READY`, then per line `OK`/`ERR`, then `STORED` after `END` | Upload: C# sends the switch-table, SVB-switch-table, dreieskive, status-LED and fade-config lines, `END` to finish |
| `SCD` | — | all five record shapes, then `END` | Download: dump everything configured, across all five tables |

Each line starts with a one-letter tag so all five record shapes share one
stream:

| Tag | Format | Meaning |
|---|---|---|
| `S` | `S <slot> <motorVAddrHex> <motorBitHex> <polarityHex> <feedbackVAddrHex> <fbRettHex> <fbAvvikHex>` | One switch-table slot |
| `P` | `P <slot> <vaddrHex> <bitPrimaryHex> <bitSecondaryHex> <targetIsDreieskiveHex> <targetSlotHex>` | One SVB-switch-table slot (`bitSecondaryHex = FF` for a plain on/off switch; `targetSlotHex` ignored when `targetIsDreieskiveHex = 1`) |
| `D` | `D <motorVAddrHex> <pinBaseHex> <cwPolarityHex>` | The dreieskive **motor** facts — always known for FSCB in Phase 1 |
| `L` | `L <vaddrHex> <bitHex>` | The status-LED fixed facts |
| `F` | `F <fadeMsHex4> <fadeStepsHex> <pwmPeriodUsHex4>` | Fade config — the only 16-bit fields on this wire (`fadeMsHex4`/`pwmPeriodUsHex4` are 4 hex digits, not 2, since `1000` doesn't fit one byte) |

`signals`/`trackDetection` (in `SystemConfig.json` already, see below) don't
have EEPROM regions or wire-line tags yet — a gap, not a deliberate
omission, since neither has functional firmware use yet (FCSBL isn't built).
Worth closing before FCSBL work actually starts, not before.

Same style as the routing matrix's `N RR AA ...` lines — hex bytes,
space-separated.

`SW`/`SR` never mention port or bit — that's the whole point. C# only ever
needs to know a slot number (which it gets from its own SVB-name/switch-number
→ slot lookup in `BoardConfig`, see below) and `R`/`A`.

---

## EEPROM layout (Phase 1, new — unrelated to old Region1–6)

Two flat, board-agnostic tables, both parallel byte arrays, both applying the
same "cheap headroom now beats a schema-breaking resize later" reasoning —
plus a handful of singleton facts that don't need a table at all.

### Fixed board facts (dreieskive, status LED)

Not part of the switch table — these aren't discovered per-slot data, they're
declared, board-specific facts straight from `PlanExtended.md`'s FSCB spec
(Port B bits 4–5 = dreieskive, bit 7 = status LED). Still EEPROM-backed like
everything else "the system needs to run standalone" — just two bytes each,
no array needed since each board has at most one of each:

| Address | Content | Size |
|---|---|---|
| `0x02` | `DreieskiveVAddr` — `0xFF` = not configured | 1 |
| `0x03` | `DreieskiveMotorPinBase` — lower of the 2-bit pair (4, per FSCB); upper is always base+1 | 1 |
| `0x04` | `DreieskiveCwPolarity` — `0xFF` = not yet determined; `0`/`1` once set | 1 |
| `0x05` | `StatusLedVAddr` | 1 |
| `0x06` | `StatusLedBit` | 1 |

This is the **motor** side of the dreieskive only (FSCB, bits 4–5 — a fixed
board fact, known now). `DreieskiveCwPolarity` stays `0xFF` through Phase 1:
resolving it needs the operator's physical control switch to already be
mapped, which is the SVB switch table below — not something Phase 1 can
determine on its own with no SVB present.

`DreieskiveVAddr`/`DreieskiveMotorPinBase` are declared, not scanned —
written from `BoardConfig`'s known constants (FSCB's fixed `(4,5)`) at the
start of a Motor Scan session, no operator interaction needed.

### Fade config

Also singleton facts, but a different kind from the ones above: not board
wiring at all, just the fade loop's timing parameters (see
[Signal lamp logic](#signal-lamp-logic-out-of-scope)) — fixed, identical for
every fade that ever runs, ported from the original
`SignalLys_2X_Momentbrytere.ino`'s `static const` values but now genuinely
editable config rather than compiled-in constants:

| Address | Content | Size |
|---|---|---|
| `0x07`–`0x08` | `FadeMs` (uint16) — total fade duration; `1000` ported from the original | 2 |
| `0x09` | `FadeSteps` (uint8) — linear step count; `60` ported from the original | 1 |
| `0x0A`–`0x0B` | `PwmPeriodUs` (uint16) — software-PWM carrier period; `1000` ported from the original | 2 |

Read once by the fade loop at the start of each fade (not re-read per step —
these don't change during a fade, only between config uploads). Populated
via `SystemConfigSession`/`SCU`, same as everything else in
`SystemConfig.json` — not something Motor Scan or any discovery flow
touches, since there's nothing to discover: the values are simply declared,
and stay at the ported defaults until someone deliberately retunes the
dimming.

### SVB switch table

A genuinely different concept from the switch table above, so it gets its
own table rather than being folded into switch or dreieskive records: the
switch table describes **SCB** wiring (a motor + its feedback, discovered by
Motor Scan). This table describes **SVB** wiring — the operator's physical
panel switches, each one assigned to control exactly one target (almost
always a specific switch's Rett/Avvik position; the dreieskive's 3-position
toggle is the one exception). Different board, different direction
(input, not output), different discovery process (Phase 2's Command 2/D
equivalent, not Motor Scan) — mixing it into the switch table would conflate
two unrelated wiring facts just because they both eventually relate to "the
same switch."

Indexed by `svbSwitchSlot` (32 capacity, same "cheap headroom" reasoning as
the switch table).

| Address | Content | Size |
|---|---|---|
| `0x120`–`0x13F` | `SvbSwVAddr[32]` — SVB chip this operator switch lives on; `0xFF` = unconfigured | 32 |
| `0x140`–`0x15F` | `SvbSwBitPrimary[32]` — bit 0–7 | 32 |
| `0x160`–`0x17F` | `SvbSwBitSecondary[32]` — bit 0–7, or `0xFF` = single-bit switch (the common case — a plain on/off panel switch has only one bit) | 32 |
| `0x180`–`0x19F` | `SvbSwKind[32]` — `0` = pens switch (drives `TargetSlot`); `1` = the dreieskive's on-off-on toggle (`BitPrimary`=CW, `BitSecondary`=CCW); `2` = the green-request push button. Was `SvbSwTargetIsDreieskive` (0/1) | 32 |
| `0x1A0`–`0x1BF` | `SvbSwTargetSlot[32]` — which switch-table `slot` this panel switch drives, when `Kind = 0` | 32 |
| `0x240`–`0x25F` | `SvbSwPort[32]` — `0` = port A, `1` = port B | 32 |
| `0x260`–`0x27F` | `SvbSwPolarity[32]` — input level that means the panel switch is at Rett (pens only, `0xFF` otherwise) | 32 |

An entry is "configured" iff `SvbSwVAddr[slot] != 0xFF`. Populated by
Config → `5` (Panel switch scan). Wire: `P <slot> <vaddr> <port> <bitPri>
<bitSec> <kind> <targetSlot> <pol>`.

**SVB panel LEDs** (48 capacity, populated by Config → `4`, Panel LED scan):

| Address | Content | Size |
|---|---|---|
| `0x280`–`0x2AF` | `PanelLedVAddr[48]` — `0xFF` = unused entry | 48 |
| `0x2B0`–`0x2DF` | `PanelLedPortBit[48]` — `bit | (isPortB << 3)` | 48 |
| `0x2E0`–`0x30F` | `PanelLedTarget[48]` — switch-table `slot` (pens), or `0xFF` = the panel's signal lamp | 48 |
| `0x310`–`0x33F` | `PanelLedRole[48]` — `0` Rett, `1` Avvik (pens); `2` Red, `3` Green1, `4` Green2 (signal) | 48 |

Wire: `Z` clears the table, then `Q <idx> <vaddr> <port> <bit> <targetSlot>
<role>` per LED. Stored only — the runtime that lights panel LEDs from switch
feedback, and the green-request algorithm, are not built yet.

### Board hardware table

Indexed by board slot (**16** capacity — plenty; the whole eventual system
per `PlanExtended.md`'s site map has ~8 boards total). Populated by `HWU`
from `hardware.json`.

| Address | Content | Size |
|---|---|---|
| `0xB0`–`0xBF` | `BoardVAddr[16]` — `0xFF` = unconfigured slot | 16 |
| `0xC0`–`0xCF` | `BoardIodirA[16]` | 16 |
| `0xD0`–`0xDF` | `BoardIodirB[16]` | 16 |
| `0xE0`–`0xEF` | `BoardGppuA[16]` | 16 |
| `0xF0`–`0xFF` | `BoardGppuB[16]` | 16 |

### Switch table

Indexed by switch `slot`. Sized for **32 slots** now (only 4 populated in
Phase 1) rather than exactly 4 — at 6 bytes/slot this costs 192 bytes out of
1024, cheap enough to avoid a schema-breaking resize the moment a second
board's switches get configured in Phase 2. Populated by `SCU`/Motor Scan.

| Address | Content | Size |
|---|---|---|
| `0x01` | Magic byte (`0xA5`) | 1 |
| `0x10`–`0x2F` | `SlotMotorVAddr[32]` — board this slot's motor lives on; `0xFF` = unconfigured | 32 |
| `0x30`–`0x4F` | `SlotMotorBit[32]` — bit 0–7 on that board's Port B | 32 |
| `0x50`–`0x6F` | `SlotPolarity[32]` — 0/1: which level = Rett | 32 |
| `0x70`–`0x8F` | `SlotFeedbackRettBit[32]` — bit 0–7 on Port A | 32 |
| `0x90`–`0xAF` | `SlotFeedbackAvvikBit[32]` — bit 0–7 on Port A | 32 |
| `0x100`–`0x11F` | `SlotFeedbackVAddr[32]` — board this slot's **feedback** lives on; independent of `SlotMotorVAddr` | 32 |

(EEPROM is 1024 bytes total — `0x120` is nowhere near the ceiling; this new
region just goes after the board hardware table at `0xB0`–`0xFF` rather than
disturbing any existing address.)

A slot is "configured" iff `SlotMotorVAddr[slot] != 0xFF`. **Motor and
feedback vaddr are independent, not assumed equal** — on a board with 2
MCP23017 chips, a switch's feedback pair can land on the *other* chip from
its motor bit, so both need their own board reference. (For FSCB specifically
— one chip — they're always the same value in practice, but the schema
doesn't get to assume that generally.) Feedback is still assumed to live on
Port A of whichever board `SlotFeedbackVAddr` names (matches `PlanExtended.md`'s
stated SCB convention); if some future board type breaks *that* assumption
too, the schema gains a feedback-port byte then — not speculatively added now.

Switch **numbers/labels** (`1`, `3`, `5/6`, `7`, and eventually SVB
name/number) are **not** stored in EEPROM at all — they're purely a
`DrammenMJKConfig`-side (`BoardConfig`) concern for operator display and for
mapping "which slot does the operator mean" during Motor Scan / Command mode.
Firmware only ever deals in slot numbers.

Dreieskive stays a fixed compile-time constant (Port B bits 4–5), not part of
the switch table, not scanned, not yet reachable from `SW`/`SR` — matches "we
should not try to find dreieskive, as that is preassigned now". Command mode
for the dreieskive (3-state, not Rett/Avvik) is future scope.

---

## DrammenMJKConfig layering (C#)

```
ArduinoConnection        — unchanged: serial I/O, ReadLoop, capture mode
ArduinoDevice             — raw discovery wrappers: McpSetDirection/
                             McpSetPullup/McpWritePort/McpReadPort/
                             McpPollChange/McpSetBit (used by MotorScan only)
                             + switch-table wrappers: DriveSwitch(slot, pos,
                             timeoutMs) / ReadSwitch(slot)  (thin wrappers
                             over SW/SR; used by CommandSession)
                             + bulk transfer: SystemConfigUpload/Download
                             (thin wrappers over SCU/SCD, same capture-mode
                             shape as RoutingMatrixUploadStart/SendLine/Finish)
                             + bulk transfer: HardwareConfigUpload/Download
                             (thin wrappers over HWU/HWD, same shape again)
HardwareConfig (new)      — `boards[]` (each with 1–2 `chips[]`) model read
                             from `hardware.json`; flattens every chip into a
                             `(vaddr, iodirA, iodirB, gppuA, gppuB)` row sent
                             over `HWU`. Phase 1: one board (FSCB), one chip.
                             Not discovered — declared straight from the
                             known site board list.
BoardConfig (new)         — SVB/switch-number ↔ slot mapping + display labels.
                             Phase 1: one hardcoded SVB entry ("Fossli",
                             SVB 1) owning FSCB's 4 switches, slots 0–3,
                             labels ["1","3","5/6","7"].
                             This is also site configuration, not hardware —
                             it's the site topology (which SVBs, which SCBs,
                             which switch numbers) from PlanExtended.md's
                             "System description", just hardcoded for now.
                             Phase 2+: belongs in SystemConfig.json alongside
                             the switch-wiring data, not a separate file —
                             both are per-site facts discovered/declared once
                             and downloaded, without touching ConfigSession,
                             CommandSession, or ArduinoDevice.
ConfigSession              — Command 1 rewritten against BoardConfig + the
                             raw Mcp* primitives (still needed — this is the
                             discovery step that populates the switch table);
                             + new `H` item wrapping HardwareConfigSession
                             (upload/download hardware.json) — run before `1`,
                             since Motor Scan assumes ports are already set up;
                             + new `J` item wrapping SystemConfigSession
                             (upload/download SystemConfig.json).
HardwareConfigSession (new) — load hardware.json, expand via HardwareConfig,
                             upload via HWU (which also applies it live); or
                             HWD → save hardware.json.
SystemConfigSession (new)  — mirrors RoutingMatrixSession: load SystemConfig.json
                             → SCU, or SCD → save SystemConfig.json. Also
                             called automatically from MotorScan after each
                             slot is stored. Deliberately *not* called
                             "hardware" — it holds discovered, per-site,
                             changeable facts (which motor drives which
                             switch, which feedback pins belong to it), not
                             fixed per-board-type hardware facts. See
                             [System configuration persistence](#system-configuration-persistence-systemconfigjson)
                             for the hardware-vs-configuration distinction
                             this naming is built on.
CommandSession (new)       — new top-level mode (sibling of DebugSession /
                             VerifySession); operates already-configured
                             switches by SVB-name + switch-number label,
                             resolved to a slot, via DriveSwitch/ReadSwitch —
                             never touches Mcp*/port/bit directly.
```

### `BoardConfig` — Phase 1 hardcoded values

An SVB owns a **list** of SCB virtual addresses, not a single one — Phase 1
only populates one entry, but Fossli will have two (Høyre + Venstre) as soon
as Phase 2 starts, and the scan algorithm below is written against the list
from day one so that addition doesn't change the loop shape, only the data.

```csharp
Svb = "Fossli" (SVB 1),
Scbs = [
    {
        Name = "Fossli Høyre (FSCB)",
        VirtualAddress = 0x20,          // bus 0, real addr 0x20 — becomes 0x40 once
                                         // FSCB is rewired to Bus 2 (see Virtual addressing)
        MotorBitRange = 0..3,           // motor bits scanned on this SCB's Port B
        Switches = [
            (Label: "1"),
            (Label: "3"),
            (Label: "5/6"),
            (Label: "7"),
        ],
        DreieskivePins = (4, 5),        // pre-assigned, not scanned, not in the switch table
        StatusLedPin = (Port.B, 7),     // informational only — firmware clears it at boot now
    },
    // Phase 2: a second entry here for Fossli Venstre (VirtualAddress = 0x41, its own
    // Switches list) is all that's needed to extend the scan/command flow to it.
],
```

Slot numbers themselves are assigned sequentially across `Scbs` in order (SCB
0's switches get slots 0..N-1, the next SCB continues from N, etc.) — the flat
slot index isn't stored in `BoardConfig`, it falls out of iteration order when
`MotorScan` writes the table.

Note the FSCB motor drive is **one pin per switch**, not the two-pin H-bridge
pair used in `PLAN_PensControl.md`'s SwitchMotors board — the 74HC14 inverter
on FSCB produces the second H-bridge line in hardware. Confirmed by
`PlanExtended.md`: "Pin 0-3 controls the switch motors. High and Low indicate
the two directions" (single pin, not a pair) and "74HC14 IC... irrelevant for
the communication".

`ArduinoDevice` gets a matching helper so config entries can be written
readably instead of as raw hex: `static byte VirtualAddress(int bus, byte realAddr) => (byte)(bus * 0x10 + realAddr)`.
E.g. the future Fossli Høyre entry would read `VirtualAddress(bus: 2, realAddr: 0x20)` → `0x40`.

### Command 1 — Motor scan (Phase 1 scope)

Per `PlanExtended.md`: only find/map the 4 switch motors + their feedback
pairs and Rett/Avvik polarity. **Do not scan for the dreieskive** — its pins
are fixed (`DreieskivePins`), and it's outside the scan loop entirely (see
below — this also means Phase 1 doesn't need the old system's "timeout =
Dreieskive" branch at all). "Not scanned" doesn't mean "not configured",
though: at the start of a Motor Scan session, before the switch loop runs,
C# writes the dreieskive and status-LED facts (`D`/`L` lines, straight from
`BoardConfig`'s known constants) so `SystemConfig.json`/EEPROM fully describe
the board from the first scan onward, not just its discovered switches. Also
determine + store open/closed (Rett/Avvik) positions by commanding the motor
and asking the operator, and let the operator assign the real-world switch
number (`1`, `3`, `5/6`, `7`) to each discovered motor pin.

#### Discovery algorithm

One fact fixes the shape of this: **which motor bit maps to which feedback
pair is exactly what's unknown** going in — the pairs themselves (`0-1`,
`2-3`, `4-5`, `6-7`) are fixed by wiring convention, but board assembly
doesn't guarantee motor bit N drives the pair starting at bit N.

What's *not* assumed (corrected from an earlier draft): that a motor's
feedback pair lives on the same chip as the motor. On a board with 2
MCP23017 chips, feedback can land on either chip — so in general the scan
needs to watch Port A on **every chip belonging to the board being scanned**,
not just the motor's own chip, and record whichever one actually changed.

Outer loop over the SVB's boards (1 entry in Phase 1: FSCB, 1 chip), for each
board inner-looping over its chips' motor bit ranges (`0..3` on FSCB's one
chip in Phase 1 — dreieskive's `4..5` is never touched by this loop):

```
for each board in Svb.Boards:
    chips = board.Chips                                          // 1 or 2 vaddrs

    for each chip in chips:
        for each motorBit in chip.MotorBitRange:
            if motorBit already assigned -> skip

            baseline[c] = MR(c, PORT_A)  for each c in chips       // baseline on EVERY chip of the board
            MBIT(chip.vaddr, PORT_B, motorBit, 0)                  // fire this motor only, polarity 0
            (fbVaddr, result) = poll every c in chips' Port A against baseline[c]
                                 until ANY of them changes, or timeoutMs elapses

            if no change on any chip:
                report "no feedback change — wiring problem?" ; offer retry/skip
                continue                                            // NOT "this is the Dreieskive": that
                                                                     // branch doesn't exist in Phase 1,
                                                                     // Dreieskive's bits are never in this loop

            diff = result.byte XOR baseline[fbVaddr]
            assert exactly 2 bits set in diff, and they form one of the 4 known
            adjacent pairs (0-1/2-3/4-5/6-7) — otherwise report an anomaly
            (unexpected bits changed) and let the operator retry/abort

            highBit = whichever of the pair's two bits is currently 1 in result.byte

            prompt operator: "which switch moved?" -> pick one of the still-unassigned
            labels on this board (or 0=skip, Esc=abort) -> slot = next free slot
            prompt operator: "is it now at R or A?" -> pos0

            // record: bit value 0 on the motor = pos0; the pair bit that's high right
            // now = pos0's feedback bit; the other pair bit = the opposite position
            SlotPolarity[slot]          = (pos0 == Rett) ? 0 : 1
            (SlotFeedbackRettBit or SlotFeedbackAvvikBit)[slot] = highBit   // whichever pos0 was
            (the other one)[slot]                                = the pair's other bit

            // verification move — not strictly required to fill the table (the pair
            // structure already implies the second bit), but drives the opposite
            // polarity and confirms the feedback pair actually flips as expected,
            // catching wiring/mechanical faults at config time rather than later
            MBIT(chip.vaddr, PORT_B, motorBit, 1)
            confirm = poll fbVaddr's Port A against result.byte, timeoutMs
            if confirm times out or doesn't land on the expected other bit:
                report "opposite position not confirmed" ; offer retry

            SlotMotorVAddr[slot]    = chip.vaddr
            SlotMotorBit[slot]      = motorBit
            SlotFeedbackVAddr[slot] = fbVaddr           // may differ from SlotMotorVAddr
            write all six regions to EEPROM (ER/EW), mark motorBit + slot done
```

**Phase 1 caveat**: "poll every chip of the board simultaneously" needs a
multi-target capability `MPOLL` doesn't have (it watches exactly one
`vaddr`/port/baseline). FSCB's board has exactly one chip, so Phase 1's own
scan never actually needs to watch more than one — `fbVaddr` is always
`chip.vaddr` in practice, and a single `MPOLL(chip.vaddr, PORT_A, baseline, timeoutMs)`
suffices, same as the previous draft. The algorithm above is written for the
general (2-chip) case because the *schema* now supports it
(`SlotFeedbackVAddr` independent of `SlotMotorVAddr`), but actually
implementing simultaneous multi-chip polling is deferred until a 2-chip
board is actually being scanned — see [Explicitly deferred](#explicitly-deferred-not-phase-1).

Each switch is scanned **to completion** (including the verification move)
before the next one starts — motors are driven one at a time deliberately, so
a feedback change on Port A can always be attributed to the motor bit that
was just fired. Two motors settling concurrently on the same board would make
the diff-pair detection ambiguous, since they'd share the same Port A
byte(s) — true whether the board has 1 or 2 chips.

Updated from an earlier draft: the scan carries the motor's `(vaddr, motorBit)`
through the loop as before, but feedback discovery is no longer assumed to
stay on that same `vaddr` — it's whichever chip of the board actually
changed, recorded separately as `SlotFeedbackVAddr`. Motor and feedback vaddr
happen to be equal for every switch on FSCB (one chip, nothing else it could
be), but the table no longer bakes that in as a rule.

"5/6" is scanned and stored exactly like any other label — one motor bit, one
feedback pair — since per the spec these two physical switches are driven and
read together as a single unit. **Open question for the user**: confirm 5 and
6 really share one motor output and one feedback pair with no way to
distinguish them electrically, since that's what determines whether this is
just a display-label nuance or a real hardware constraint worth flagging back.

Commands 2/3/4/M/D and the routing matrix stay out of the Phase 1 menu — the
existing `ConfigSession` menu should show only item `1` for now (per
`PlanExtended.md`: "For phase 1, we will only need to cover item 1"). Leave
the other menu entries commented out or behind a feature flag rather than
deleted, since their logic (LED mapping, switch mapping) will very likely be
reusable in Phase 2 once ported to the generic Mcp* primitives.

### System configuration persistence (`SystemConfig.json`)

**Hardware vs. configuration, precisely**: hardware is whatever is true for
every board of a given *type*, fixed by its PCB/schematic, regardless of
where it's installed — e.g. "an SCB's Port B is output, Port A is
input+pullup". Motor Scan never discovers that; it's a board-design constant
(currently just hardcoded per Phase 1's single board type, see
[Explicitly deferred](#explicitly-deferred-not-phase-1)). Everything Motor
Scan *does* discover — which motor bit drives which switch, which feedback
pins belong to it, its Rett/Avvik polarity — depends on how *this specific
installation's* cabinet got wired, and would differ on an otherwise-identical
board wired up differently. That's **configuration**, not hardware, and so is
`BoardConfig`'s SVB/switch-number/label topology (Phase 1: hardcoded; Phase
2+: belongs in this same file, not compiled into C#).

So the file is named `SystemConfig.json`, not `hardware.json` — same naming
principle as before (match what the file actually is), corrected: what it
holds is discovered/declared per-site configuration, not physical hardware
facts. Same reasoning as why the LED routing matrix file is named for what
*it* is (`FossliSwitchMatrix.json`, a routing matrix) rather than something
generic.

EEPROM is the only thing firmware reads at runtime, but it's a single point
of failure — a reset, a chip swap, or a new Arduino would otherwise mean
physically re-running Motor Scan (walking every switch motor by hand again)
just to rediscover wiring that hasn't actually changed. **The upload path
exists specifically to avoid that**: as long as the switch-table schema is
unchanged (same regions/record layout — the common case by far, since it only
breaks across a firmware upgrade that changes the EEPROM layout itself), the
saved `SystemConfig.json` alone is enough to repopulate EEPROM. Re-scanning is
only actually required when the physical wiring itself changed — not for a
blank/replaced EEPROM or Arduino.

- **Written automatically**: after each slot is confirmed during Motor Scan
  (not just at the end — so an aborted scan still leaves a `SystemConfig.json`
  that matches whatever EEPROM actually has).
- **`J` — new `ConfigSession` menu item** ("System config (upload/download
  SystemConfig.json)"), alongside `1`, offering:
  - **Download**: `SCD` → read every configured slot back from EEPROM, write/overwrite `SystemConfig.json`. Useful to regenerate the file if it's ever missing or stale.
  - **Upload**: read `SystemConfig.json`, send `SCU` + one line per switch, `END` → restores EEPROM from a saved file, e.g. after an EEPROM/Arduino replacement, with no physical re-scan.
- EEPROM remains authoritative for what firmware actually runs against —
  `SystemConfig.json` is a mirror, not a second source of truth firmware ever
  reads from directly.

Keyed by switch **label**, not raw slot number, so the file stays meaningful
if slot numbering ever shifts (e.g. Region reshuffle, or Phase 2 inserting a
second SCB's switches ahead of these in slot order). Nested under a
`"switches"` section specifically so the file has room to grow a second
top-level section later (Phase 2's `BoardConfig` topology — SVBs, SCBs, which
switch numbers belong to which — also site configuration, so it belongs here
too) without a breaking format change:

Actual file: `DrammenMJKConfig/SystemConfig.json`. It carries a top-level
`"_todo"` array — plain strings, not consumed by any code, just a place to
record open questions directly in the file itself rather than losing them in
chat history (JSON has no comment syntax, this is the pragmatic substitute):

```json
{
  "_todo": [
    "FCSBL's switch labels are now known: 101, 2, 4 (matching the older letter-based system's Pens B, C, D at Fossli). Not yet in the switches section below -- that section means 'discovered wiring', and only the labels are known so far, not which of motor bits 0,1,2 is which. A Motor-Scan-style pass (fire each bit, ask the operator which switch moved) is what fills that in, same process as FCSBR; the physical facts needed to run that scan (motor bits 0,1,2 on vaddr 0x21; feedback pairs (0,1)/(2,3)/(4,5) on the same chip) are already known from hardware.json.",
    "FCSBL drives one signal (3 lamps: Red, Green1, Green2) on Port B bits 4,5,6 -- range now known, but which specific bit is which color is not. The doc also says 'we have two of these, so they should be numbered' -- Fossli has 2 signals station-wide (mirroring the original DualSignal's Signal A/B), but only one is confirmed to be on FCSBL. Where the second signal lives is not yet stated; only one signals entry is populated below.",
    "Signal numbering is explicitly deferred in PlanExtended.md ('The letters we use there is now converted to numbers. Will come back to that.') -- the signals section below stays structurally unconfigured even though the candidate bits are known.",
    "Track detection is now known to be Port A bit 7 on 0x21 (below). Its polarity (which level = train present) still needs configuring -- same as the old DualSignal system's active-HIGH Train input, which was the one input that didn't follow the usual active-low convention.",
    "fadeConfig values are the original SignalLys_2X_Momentbrytere.ino defaults (FadeMs=1000, FadeSteps=60, PwmPeriodUs=1000), ported as-is rather than recomputed. Unlike the original's hardcoded static const, these are now genuine config -- editable here without a firmware recompile -- but nobody has had a reason to change them yet, so they stay at the values already proven on the original hardware."
  ],
  "site": "Fossli",
  "svb": "Fossli",
  "switches": {
    "1":   { "motorVAddr": "0x20", "motorBit": 0, "polarity": 0, "feedbackVAddr": "0x20", "feedbackRettBit": 0, "feedbackAvvikBit": 1 },
    "3":   { "motorVAddr": "0x20", "motorBit": 1, "polarity": 1, "feedbackVAddr": "0x20", "feedbackRettBit": 3, "feedbackAvvikBit": 2 },
    "5/6": { "motorVAddr": "0x20", "motorBit": 2, "polarity": 0, "feedbackVAddr": "0x20", "feedbackRettBit": 4, "feedbackAvvikBit": 5 },
    "7":   { "motorVAddr": "0x20", "motorBit": 3, "polarity": 0, "feedbackVAddr": "0x20", "feedbackRettBit": 6, "feedbackAvvikBit": 7 }
  },
  "dreieskive": {
    "motorVAddr": "0x20",
    "motorPinBase": 4,
    "cwPolarity": null
  },
  "statusLed": {
    "vaddr": "0x20",
    "bit": 7
  },
  "svbSwitches": {
    "1":          { "vaddr": null, "bit": null },
    "3":          { "vaddr": null, "bit": null },
    "5/6":        { "vaddr": null, "bit": null },
    "7":          { "vaddr": null, "bit": null },
    "dreieskive": { "vaddr": null, "bitCw": null, "bitCcw": null }
  },
  "signals": {
    "1": { "vaddr": "0x21", "redBit": null, "green1Bit": null, "green2Bit": null }
  },
  "trackDetection": {
    "vaddr": "0x21",
    "bit": 7,
    "activeHigh": null
  },
  "fadeConfig": {
    "fadeMs": 1000,
    "fadeSteps": 60,
    "pwmPeriodUs": 1000
  }
}
```

`motorVAddr`/`feedbackVAddr` (split from a single `vaddr` field — a switch's
feedback can land on a different chip than its motor, on boards with 2
MCP23017s; see [Discovery algorithm](#discovery-algorithm)) are deliberately
just the address, not a board name: the name lives once, in `hardware.json`
(cross-reference `boards[].chips[].vaddr` there), not duplicated here so the
two files can't drift out of sync with each other. On FCSBR both fields are
always `"0x20"` since it's a single-chip board — the split only matters once
a 2-chip board's switches get scanned.

`statusLed` is a fixed FCSBR fact (Port B bit 7 per `PlanExtended.md`), not
discovered — same category as the switches ("what this pin is for", not
direction/pull-up, so it belongs here rather than in `hardware.json`).

`dreieskive` here is the **motor** side only (FCSBR, bits 4–5, a fixed board
fact, known now — mirroring the two-pin encoding `ArduinoDevice.cs`'s older
`Region5MotorPin`/`Pol` fields used for the same concept). `cwPolarity` stays
`null` in Phase 1 — resolving it needs the matching entry in `svbSwitches`
below to exist first.

`signals`/`trackDetection` are new sections, added straight from FCSBL's
spec: FCSBL drives one signal (`redBit`/`green1Bit`/`green2Bit`, all still
`null`) and reads a single track-detection bit whose active level isn't
determined yet (`activeHigh: null`) — same shape reasoning as everything
else here, wiring facts declared or discovered, never invented. Neither
section models the *signal-lamp state machine itself* (Direction, PWM
dimming, train-present timeout — see
[Signal lamp logic](#signal-lamp-logic-out-of-scope)) — that stays pure
firmware logic with no config surface, exactly like the original DualSignal
system, where only pin *assignment* was configurable, never the behavior.

`svbSwitches` is a genuinely separate concept from `switches`/`dreieskive`
(matches the [SVB switch table](#svb-switch-table) EEPROM split): every SVB
panel switch is assigned to exactly one target — a switch's Rett/Avvik
position (`bit`, single bit — a plain on/off toggle) or, for the one
exception, the dreieskive's 3-position toggle (`bitCw`/`bitCcw`, two bits,
per `PlanExtended.md`'s "toggle switch on1/off/on2 ... use two bits" SVB
input). Keyed by the same label space as `switches` (plus the special
`"dreieskive"` key) so the two sections read as two facts about the same
named things, not unrelated tables. `cwPolarity` above is what a future
runtime loop uses together with `svbSwitches.dreieskive` to translate "the
SVB's CW bit went active" into "drive these two SCB motor bits to whichever
pattern is actually clockwise" — same role `polarity` plays linking a normal
switch's `svbSwitches` entry to its `switches` entry.

Every `svbSwitches` value stays `null` through all of Phase 1: Phase 1 has no
SVB at all, so there's nothing to discover yet — this section (like
`dreieskive.cwPolarity`) is scaffolding for Phase 2's manual-switch and
dreieskive-switch discovery flows, not something Phase 1 populates.

On upload, C# resolves each label back to its slot via `BoardConfig` (the
same label list Motor Scan uses) before sending the `S` lines, and sends the
`dreieskive`/`statusLed`/`svbSwitches` sections as the `D`/`L`/`P` lines — so
the file itself never needs to know about EEPROM slot numbers at all, only
labels + wiring facts.

### Command mode (new top-level mode, `CommandSession`)

Per `PlanExtended.md`: "add a command mode, so we can send direct commands to
the switch motors, by giving their number... That way we can actually operate
the switches from the PC" — and per the follow-up correction, addressed by
**SVB name/number + switch number**, not by raw pin.

Added as a new top-level entry alongside `C`/`D`/`V`/`Q` in `Program.cs`
(e.g. `O` — Operate), not squeezed into `ConfigSession`, since it's a runtime
operation mode, not a discovery/config one.

Flow:
1. Operator types a switch number (`1`, `3`, `5/6`, `7`) — reject if
   `BoardConfig` has no slot for it, or the slot's EEPROM entry is still
   unconfigured ("run Motor scan first").
2. Operator types the target position (`R`=Rett/closed, `A`=Avvik/open — reuse
   the existing R/A convention, not O/C).
3. C# resolves the label to a slot and calls `DriveSwitch(slot, pos, timeoutMs)` → `SW <slot> <pos> <timeoutMs>`. All the port/bit/polarity resolution happens in firmware.
4. Report the result (`RETT`/`AVVIK`/`BETWEEN`/`TIMEOUT`) to the operator.
5. `Esc` returns to the top-level menu.

Since `SW` already blocks until the motor settles or times out, there's no
separate poll step on the C# side — this is simpler than the original
Mcp*-based sketch, precisely because port/bit resolution moved server-side.

---

## Runtime / production behavior (design note, not Phase 1 scope)

Not built in Phase 1, but this is *why* the switch table lives in firmware
rather than C#: eventually the CB polls each SVB's panel-switch input port,
and on a change, looks up the corresponding slot and calls the same internal
`resolve_switch()` + drive logic that `SW` calls today — no PC involved, no
protocol change needed. Phase 1's `SW`/`SR` are literally "manually invoke the
function the runtime loop will call automatically later." Getting the
table/resolver shape right now avoids reworking it when that loop is built.

**Device state — per device, not global.** Every physical board (one entry
per `vaddr` in the board hardware table) carries its own state, independent
of every other board's:

| State | Meaning |
|---|---|
| `UNINITIALIZED` | Every device starts here at power-up, before anything's been checked |
| `CONFIGURATION` | The PC config tool is actively driving *this* device (Motor Scan, Command Mode, `hardware.json`/`SystemConfig.json` upload targeting it) |
| `NORMAL` | Standard runtime — this device's inputs/outputs respond to events as usual |
| `FADING` | This device is running a blocking fade (only ever reachable on the two boards that can fade at all — FCSBL, MotorVallekilen) |

Transitions, per device, each power session:

- **First time ever** (this `vaddr` has no entry in the EEPROM board
  hardware table yet — the existing `BoardVAddr[i] != 0xFF` check already
  answers this): `UNINITIALIZED → CONFIGURATION → NORMAL`. It has to be
  configured via the PC tool before it can run.
- **Every subsequent boot** (already configured): `UNINITIALIZED → NORMAL`
  directly — no config session needed, same distinction the boot-time
  hardware bring-up already makes.
- **PC config tool connects and targets this device** (even one already
  configured — re-running Motor Scan, Command Mode, a fresh upload):
  `NORMAL → CONFIGURATION`, back to `NORMAL` when that session ends.
- **A fade starts** (fading-capable devices only): `NORMAL → FADING`, back
  to `NORMAL` when the fade's blocking call returns.

What this buys, precisely, and corrected from an earlier draft that got the
scope wrong: `FADING` blocks messages **to that one device**, not messages
in general. Between individual I2C transactions the Arduino is free — it
isn't locked into an uninterruptible ~1-second block just because one device
is fading. Before any I2C message goes out, the check is "is the *target*
device currently `FADING`?" — if the message is for the fading device
itself, it queues until that device is back to `NORMAL`; if it's for any
other device (`NORMAL`, regardless of what the fading device is doing), it
goes out immediately, interleaved between the fading device's own toggle
writes. See [Signal lamp logic](#signal-lamp-logic-out-of-scope) for how the
fade loop's own wait is structured to make room for that. The states are
also reusable for things unrelated to fading, e.g. rejecting an `SW` sent to
a device still in `CONFIGURATION`.

**Port-output state: one shadow byte per port, shared by every writer of
that port.** "Persistent" in an earlier draft was a misleading label — every
piece of RAM state here lives for the same lifetime (until reboot), so
naming one shadow "persistent" as if it were a different kind of thing from
another was the confusing part, not the mechanism itself. There's just one
shadow per physical register, full stop.

This is a deliberate exception to `MBIT`'s "always read live hardware, never
cache" rule (see [Command mode](#command-mode-new-top-level-mode-commandsession)),
justified by boot-time necessity rather than performance: at boot, the
runtime loop has to read every SVB switch on a board and compute one
combined motor-pattern byte before writing anything to that SCB's Port B —
that computed byte **is** a shadow whether it's named one or not. From then
on it's simply kept accurate: seeded once, updated in place by every write,
never re-read.

**Why one shadow, not one per concern.** On a board where more than one
runtime concern writes the same physical register — FCSBL's Port B holds
both the motor bits (0–2) and the signal-LED bits (4–6, driven by the fade
loop, see below — Signal lamp logic) — those two concerns write **disjoint
bitmasks** of the same byte. A motor-bit write only ever touches bits 0–2
(`shadow = (shadow & ~motorMask) | motorBits`); a fade toggle only ever
touches bits 4–6. Neither needs to know anything about the other's pending
change — each just leaves whatever's already in the bits it doesn't own
alone, which is automatically correct as long as both are reading and
writing the *same* shadow. Two independent copies (an earlier draft's
mistake) would let them drift the moment both fired close together, since
neither would see the other's update.

**The only real requirement: writes can't interleave with each other.**
"Compute the new byte from the shadow → send it over I2C → update the
shadow" has to run to completion as one unit before another writer touches
the same shadow — not because the *bits* conflict (they don't, being
disjoint), but because two writers could otherwise both read the same stale
shadow and each write back a version missing the other's change. This holds
by construction here, not by adding locks: the ISR (`PlanExtended.md`'s INTA
wiring, deferred past Phase 1) is only ever allowed to set a flag and return
— it never calls `Wire`/I2C or touches the shadow directly, both because
Arduino's `Wire` library isn't ISR-safe regardless of this design, and
because it's what keeps every actual write single-threaded on the main
loop. Given that, there is no code path that can interrupt a write already
in progress — "blocked writing" is automatic, not something that needs
explicit `noInterrupts()`/`interrupts()` guarding, *as long as that one rule
(ISRs never write) keeps holding*. Worth a comment at the ISR call site
saying so, since it's the kind of invariant that breaks silently if someone
later "simplifies" by writing directly from an interrupt handler.

Deliberately **not** used by `MBIT`/Motor Scan/Command Mode, which keep
reading live hardware on every operation exactly as designed — those are
infrequent, human-paced, interactive operations where anchoring every write
to the register's actual current content matters more than avoiding one
extra I2C read (see [System configuration persistence](#system-configuration-persistence-systemconfigjson)
for what that read-first behavior actually buys: no accumulated drift, and a
failed read is visible at the point of the read rather than laundered into a
wrong write later).

One residual risk, accepted rather than silently ignored: if an SCB chip
resets or glitches independently *while the Arduino keeps running* (not a
full power-cycle — that resets the shadow along with it and is
self-correcting), the shadow has no way to detect the mismatch and would
keep pushing stale bits back. Not a reason to reject the shadow — that
failure mode is rare, and read-modify-write on every poll cycle across every
switch system-wide would be real, ongoing I2C overhead for a benefit that
almost never materializes. A cheap, non-urgent hardening for later: a
periodic full resync (re-apply the shadow to hardware every so often
regardless of whether a change was detected), not built now.

## Signal lamp logic (out of scope)

The original DualSignal signal-lamp behavior (`SPECS.md`, actual source:
`SignalLys_2X_Momentbrytere/SignalLys_2X_Momentbrytere.ino`) needs gradual
dimming during lamp transitions (not just steady on/off), which is a hard
real-time concern — it will be **ported natively into firmware** when it's
built, not decomposed into portable "generic" C#-driven rules the way the
switch config logic was. Phase 1 has no lamps or SVBs at all, so this is
purely a heads-up for later phases: don't expect the lamp state machine to
follow the "logic lives in C#" pattern used elsewhere in this plan.

**Dimming mechanism, confirmed**: the original code uses **software PWM**
throughout, never `analogWrite`/hardware timers, even on the pins that could
support it (D9/D10/D11 are hardware-PWM-capable, D7/D8/D12 aren't — uniform
software PWM sidesteps having some lamps fade differently than others).
`FadeGroup()`'s algorithm: a 1-second fade (`FadeMs = 1000`) in 60 linear
steps (`FadeSteps = 60`), each step busy-toggling the target pin(s) HIGH then
LOW for `duty`/`(255-duty)` fractions of a 1ms period (`PwmPeriodUs = 1000`)
via `digitalWrite` + `delayMicroseconds` — entirely blocking for the fade's
duration. `ApplyNormalOutputsSlowly()` diffs the desired lamp state against
current state on a direction/track change, splits into "fading off" and
"fading on" groups, and fades them sequentially.

Per direction: **port the algorithm exactly** — same constants, same 60-step
linear timing, same visual result — but the original's waiting mechanism
(`delayMicroseconds`, a hard busy-wait) doesn't port as directly as the rest
of it, and stated precisely in terms of
[Device state](#runtime--production-behavior-design-note-not-phase-1-scope)
above, here's why: in the original, there was nothing else the MCU could
usefully do during that wait (one board, no I2C, no other devices), so a
hard busy-wait cost nothing. That's no longer true — this system has ~10
I2C devices, and blocking all of them for up to a second because *one*
device (FCSBL or MotorVallekilen) is fading would be real, avoidable
collateral damage, not an inherent cost of the port.

So the fade's wait becomes **deadline-polling, not blocking**: instead of
`delayMicroseconds(highUs)`, compute the target timestamp via `micros()` and
loop until it's reached — and inside that loop, service any pending message
whose *target* device is not the one currently `FADING`, exactly as
[Device state](#runtime--production-behavior-design-note-not-phase-1-scope)
describes. A message for a `NORMAL` device goes out immediately, interleaved
between the fading device's own toggle writes; only a message for the
fading device itself queues until it's back to `NORMAL`. Same-bus devices
interleave for the cost of one extra I2C transaction; a device on a
*different* bus costs an extra mux channel switch there and back (to return
to the fading device's bus in time for its next toggle) — more overhead,
still far cheaper than making every other bus wait up to a second. At the
extremes of duty cycle one phase can be too short to fit an extra
transaction (near 0% or 100%, one of `highUs`/`lowUs` approaches zero) — the
loop should skip interleaving when there isn't enough of the window left,
not stall the fade to force one through.

**Scope, precisely**: only two of the ~10 MCP devices in the whole system
can ever reach `FADING` at all — FCSBL (Fossli Venstre) and MotorVallekilen,
the only boards that combine motor-driving and signal-fading on the same
chip. The other 8 never run a blocking fade loop and never leave `NORMAL`
for this reason — and per the redesign above, their own pending events don't
even need to wait for someone else's fade, only a message addressed to the
fading device itself does.

**What the fade loop owns beyond the shared shadow.** Not everything about a
fade belongs in the port shadow — that byte only ever holds "what's
currently written to hardware." Three more pieces of state exist, and
they're not all the same *kind* of state — worth not bundling them together
the way an earlier draft did:

- **Fade parameters** — `FadeMs` (total duration), `FadeSteps` (step count),
  `PwmPeriodUs` (software-PWM carrier period) — **config, not per-call
  state**: identical for every fade that ever runs, set once, read every
  time. Same category as everything else tunable in this plan, so they
  belong in `SystemConfig.json` (a new `fadeConfig` section) rather than
  hardcoded — see below.
- **The end value** — the target pattern the fade is converging toward (the
  original's `desired[]`, computed fresh by the `ApplyNormalOutputsSlowly()`
  port on every direction/track-state change). Scoped to one fade call.
- **Fade progress** — genuinely transient, reset every call: which of the
  `FadeSteps` steps it's on, the current duty, the step deadline. Purely
  local loop state, never written to hardware, never shared with anything
  else, and the only one of the three that actually changes *during* a fade.

None of these three is a second copy of the shadow, so there's nothing to
keep in sync between them and it — the fade reads its parameters once,
computes each step's target byte from the end value and its progress state,
applies it to the *one* shared shadow via its bitmask (bits 4–6 only), and
writes.

That leaves interrupts. Two cases, and they resolve differently:

- **Track detection is a read, not a write, so it was never a collision
  risk in the first place** — on any device, fading or not. It's on Port A;
  the fade only ever writes Port B. Those are physically distinct MCP23017
  registers (separate register addresses for GPIO/OLAT per port) — reading
  Port A at any moment, mid-fade or not, never touches what's sitting in
  Port B's OLAT. This was never blocked on anything and doesn't need the
  interleaving mechanism above at all.
- **A switch command on the *fading device itself* has to wait** — that
  does mean a motor write to Port B, the same register the fade is
  toggling, so it's a genuine same-shadow conflict (see Port-output state
  above). But the fade is at most 1 second, and the physical switch motor's
  own throw time is "way above that", so queuing it costs nothing
  meaningful. A switch command on **any other device**, though, isn't in
  this situation at all — that device isn't `FADING`, so per
  [Device state](#runtime--production-behavior-design-note-not-phase-1-scope)
  its message just goes out, interleaved into the fading device's wait
  windows like anything else targeting a `NORMAL` device.

The ISR still does the absolute minimum — record that something changed (a
`volatile` flag, tagged with which device it's for) and return, never
touching `Wire`/I2C or the shadow directly, since `Wire` isn't ISR-safe
regardless of any of this design. `FadeGroup`'s deadline-polling loop
(described above) is what actually drains that queue: on every wait-window
check, service any pending message for a device that isn't the one fading;
leave a pending message for the fading device itself queued. Once the fade
finishes and the device transitions `FADING → NORMAL`, that last
device-specific message is serviced against the **shared** port shadow —
correctly, because the shadow already reflects wherever the fade left the
signal bits, so it preserves them automatically without having needed to
coordinate with the fade while it ran.

---

## Task order

1. `git mv`/copy `Simulator/Simulator.ino` → `Firmware/Firmware.ino`.
2. Strip all simulated-Pens state/business logic; keep `readLine`, `dispatch`,
   `ok()`/`errCmd()`/`status()` helpers, and the `PING`/`SI`/`ER`/`EW`/`EC`/`RST`
   handlers (these operate on the Arduino's own EEPROM, no hardware change needed).
3. Add `Wire.h` + the 3-primitive generic MCP23017 driver (`mcp_write_reg`,
   `mcp_read_reg`, direction/pullup helpers) — same shape as
   `PLAN_Refactor.md`'s driver, reference `Firmware_FirstAttempt`'s
   `mcp_write`/`mcp_read` for the register-access pattern only.
4. Add the virtual-address resolver (`resolve_vaddr(vaddr) -> {bus, real_addr}`) and `i2c_select_bus(uint8_t bus)`; Phase 1 the latter is a validating no-op (only `bus==0` is legal).
5. Add the board hardware table EEPROM regions + `resolve_board_hw(vaddr)` reader, and the data-driven boot-time bring-up routine that applies every configured entry (IODIR/GPPU/OLAT=0x00).
6. Implement `MDIR` / `MPU` / `MW` / `MR` / `MPOLL` / `MBIT` dispatch handlers, each going through the resolver.
7. Implement `HWU` / `HWD` bulk transfer dispatch handlers for the board hardware table (`HWU` also re-runs the boot-time bring-up routine live after storing).
8. Add the switch-table EEPROM regions + `resolve_switch(slot)` reader.
9. Implement `SW` / `SR` dispatch handlers on top of `resolve_switch()`.
10. Implement `SCU` / `SCD` bulk transfer dispatch handlers (same shape as the existing `RMU`/`RMD` handlers, just against the switch-table regions instead of Region6).
11. Bench test against FSCB directly: manual `HWU` with a hand-built line, confirm GPB7 LED goes off, then `MDIR`/`MW`/`MR` to sanity-check Port A feedback reads pull-up idle-high correctly.
12. `DrammenMJKConfig`: add `HardwareConfig` (`hardware.json` model) and the `HardwareConfigUpload`/`Download` wrappers, the raw `Mcp*` wrappers (`MotorScan`-only), and the `DriveSwitch`/`ReadSwitch` + `SystemConfigUpload`/`Download` wrappers to `ArduinoDevice`.
13. `DrammenMJKConfig`: add `BoardConfig` with the hardcoded Fossli/FSCB/4-switch descriptor.
14. `DrammenMJKConfig`: add `HardwareConfigSession` (`hardware.json` ⇄ `HWU`/`HWD`) and wire it into `ConfigSession` as item `H`.
15. `DrammenMJKConfig`: rewrite `MotorScan` for the 4-switch/no-dreieskive Phase 1 scope, targeting `BoardConfig` + raw `Mcp*` calls, writing all six switch-table regions (including the separate `SlotFeedbackVAddr`) per discovered slot, and updating `SystemConfig.json` after each slot is stored; also write the fixed dreieskive/status-LED facts (`DreieskiveVAddr`/`DreieskiveMotorPinBase`/`StatusLedVAddr`/`StatusLedBit`) at scan start, straight from `BoardConfig`, before the switch loop runs.
16. `DrammenMJKConfig`: add `SystemConfigSession` (`SystemConfig.json` ⇄ `SCU`/`SCD`) and wire it into `ConfigSession` as item `J`.
17. Trim `ConfigSession`'s menu to items `H`, `1`, and `J` only (comment out 2/3/4/M/D/R, or gate behind a constant) — reassess once Phase 2 boards exist.
18. `DrammenMJKConfig`: add `CommandSession` + wire it into `Program.cs`'s top-level menu (`O` — Operate), using `DriveSwitch`/`ReadSwitch` only.
19. End-to-end run against real FSCB hardware: power up with a blank EEPROM and confirm nothing happens (no board hardware table yet); upload `hardware.json` via `H` and confirm the status LED clears itself immediately, without a reboot; run Motor Scan and confirm `SystemConfig.json` is written; power-cycle with no PC attached and confirm the LED still clears itself automatically; erase EEPROM (`R`), re-upload `hardware.json` **and** restore `SystemConfig.json` via `J`'s upload **without touching the switch hardware**, confirming Command mode still works afterward.

---

## Explicitly deferred (not Phase 1)

- INTA/interrupt-driven feedback (spec says polling only for now).
- The physical I2C mux and its channel-select mechanism — the *address encoding*
  (`vaddr = bus*0x10 + real_addr`) is now settled and implemented in the
  resolver, but `i2c_select_bus()`'s body (which register/command actually
  switches the mux to a given bus) is a no-op until the mux hardware/datasheet
  is in hand.
- The other 7 boards' `hardware.json` entries (their actual per-chip port
  arrays) — not deferred as a mechanism (`hardware.json`, `HWU`/`HWD`, the
  board hardware table, the boot-time bring-up routine are all already
  generic and board-count-agnostic), just nothing to declare yet since Phase 1
  only has FSCB. Adding any of them later is purely a data change: one more
  entry in the `boards` array.
- Simultaneous multi-chip feedback polling during Motor Scan. The switch-table
  schema already supports a switch's feedback landing on a different chip
  than its motor (`SlotFeedbackVAddr` independent of `SlotMotorVAddr`), but
  `MPOLL` only watches one `vaddr` at a time — actually discovering feedback
  on the *other* chip of a 2-chip board needs a poll that watches all of a
  board's chips together and reports which one changed. FSCB is single-chip,
  so Phase 1 never needs this; build it when the first 2-chip board (e.g. an
  SVB) is actually scanned.
- Populating the SVB switch table (`svbSwitches` in `SystemConfig.json`,
  `SvbSw*` in EEPROM) and `dreieskive.cwPolarity` — needs a Phase 2 discovery
  flow (the old system's "Command 2 — Manual switch → Pens mapping" and
  "Command D — Dreieskive switch" both apply here, adapted to the new
  schema) and an actual SVB board to run it against, neither of which Phase 1
  has. The table itself is built now; nothing in it is populated yet.
- The other 4 SCBs, 2 SVBs, and Vallekilen's combined SCB+SVB pair — including
  the mixed-port cases `PlanExtended.md`'s "Hardware configuration" section
  describes (a motor bit on an otherwise-LED SVB port, a 3-position toggle
  input using 2 bits). The per-bit `hardware.json` schema already handles
  these structurally; there's just nothing to declare yet since Phase 1 only
  has FSCB, which is uniform per port.
- Track-signal LEDs with dimming (`PlanExtended.md`: "Signals on track (3
  leds), used with dimming up/down") living on SCB outputs — same real-time
  PWM concern as [Signal lamp logic](#signal-lamp-logic-out-of-scope), just
  now confirmed to be SCB-hosted rather than only on the original DualSignal
  board. Still native-firmware scope when built, still out of Phase 1 (FSCB
  has no signal outputs).
- Multi-board topology config (moving `BoardConfig` from a hardcoded C# value
  into `SystemConfig.json` alongside the switch-wiring section) — worth doing
  as soon as board #2 shows up, not before.
- The autonomous SVB-event-driven runtime loop (see [Runtime / production behavior](#runtime--production-behavior-design-note-not-phase-1-scope)) — Phase 1 only builds the table + resolver + manual trigger (`SW`/`SR`), not the loop that will call them automatically.
- Signal-lamp PWM/dimming logic ported from the old DualSignal firmware (see [Signal lamp logic](#signal-lamp-logic-out-of-scope)).
- The second Arduino + 2×16 display.
- Reconciling/porting the older Pens-letter (A–Z) EEPROM regions and menu commands (2/3/4/M/D) onto the new generic `Mcp*`/switch-table primitives.

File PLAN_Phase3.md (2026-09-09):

# Plan: Phase 3

Collects Phase 3 scope as it's decided, same pattern as `PLAN_Phase2.md`.

## Site scale: 9 boards, moving BoardConfig.cs to JSON

Declared facts from the site owner:

- **9 boards total**, all built around the MCP23017 like FCSBR/FCSBL, but
  each genuinely different, not variations pulled from a shared template.
- Of those 9: **6 are SCB** (drive switch motors — "switches/penser", the
  physical points themselves, matching the old Pens A-Z naming), **2 are
  SVB** (stillverk — operator panel switches only, driving nothing directly;
  "stillverk" is the interlocking/panel-control side, not the motor side —
  corrected from an earlier misreading in this doc), **1 is combined**
  (drives switch motors *and* reads operator panel switches on the same
  physical board). 6+2+1 = 9.
- The two boards built so far are named **"Fossli Motors Hoyre"** and
  **"Fossli Motors Venstre"** — differs from what's currently in
  `BoardConfig.cs` (`"Fossli Hoyre (FCSBR)"` / `"Fossli Venstre (FCSBL)"`).
  Real correction to make when this gets implemented, not applied yet
  (plan-only for now).
- **All but one of the SCB-capable boards have the active status LED.**
  Today `StatusLedPin` is a required field on `BoardScb` (not yet made
  optional) — confirms it needs to become optional, the same way
  `DreieskivePins` already did.
- **Only one board has a dreieskive** — matches what's already built
  (`DreieskivePins` nullable, only FCSBR populates it). No further change
  needed here specifically.
- **`BoardConfig.cs` should move to a JSON file.** Hardcoding 9 genuinely
  different boards in C# doesn't fit this project's established pattern
  (`hardware.json`/`SystemConfig.json` for declared/discovered facts) —
  board topology (name, category, vaddr(s), switches, motor-bit-count,
  dreieskive presence, status-LED presence) should be declared data too, not
  compiled in.
- Only FCSBR/FCSBL are concretely specified so far; **the other 7 come
  later**. For now the goal is just making sure the architecture has *room*
  for this variation, not full implementation.

### Motor drive: one bit vs. two bits (resolved, can wait until the next board)

Some boards drive each switch motor with one MCU-controlled bit (like
FCSBR/FCSBL today), others with two. Simpler than it first looked once
clarified — **EEPROM only ever needs to store one bit number per switch,
plus one board-level flag**, not a whole second per-switch field:

- **The second pin, when used, is always `motorBit + 1`** (successive) —
  never needs its own stored value.
- So the only new EEPROM fact is a **board-level** "this board drives with
  two pins" flag (not per-switch) — belongs next to the board hardware table
  entry, alongside IODIR/GPPU, not in the switch table.
- **Same H-bridge driver circuit either way.** The difference is upstream:
  one-bit boards generate the second H-bridge line from an **external
  inverter** (matches `PLAN_Phase1.md`'s note about FSCB's 74HC14 producing
  the second line in hardware, "irrelevant for the communication") — the MCU
  only ever touches one bit regardless. Two-bit boards drive both lines
  directly from the MCP23017, no inverter.
- **Two inverter variants exist**: one needs an enable step after power-up
  before it works, the other doesn't. For one-bit boards using the
  needs-enabling variant, firmware needs to actively drive that enable line
  at bring-up (likely alongside `apply_board_hw()`'s existing per-board
  bring-up sequence) — an additional per-board fact: does this board have an
  inverter-enable pin, and if so, which vaddr+bit.
- `cmdSW`'s drive logic and `MotorScan`'s fire step both need to branch on
  the board-level two-pin flag (fire/drive one bit, or two successive bits
  together) — not yet implemented, deferred until the first two-bit board
  actually arrives.
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

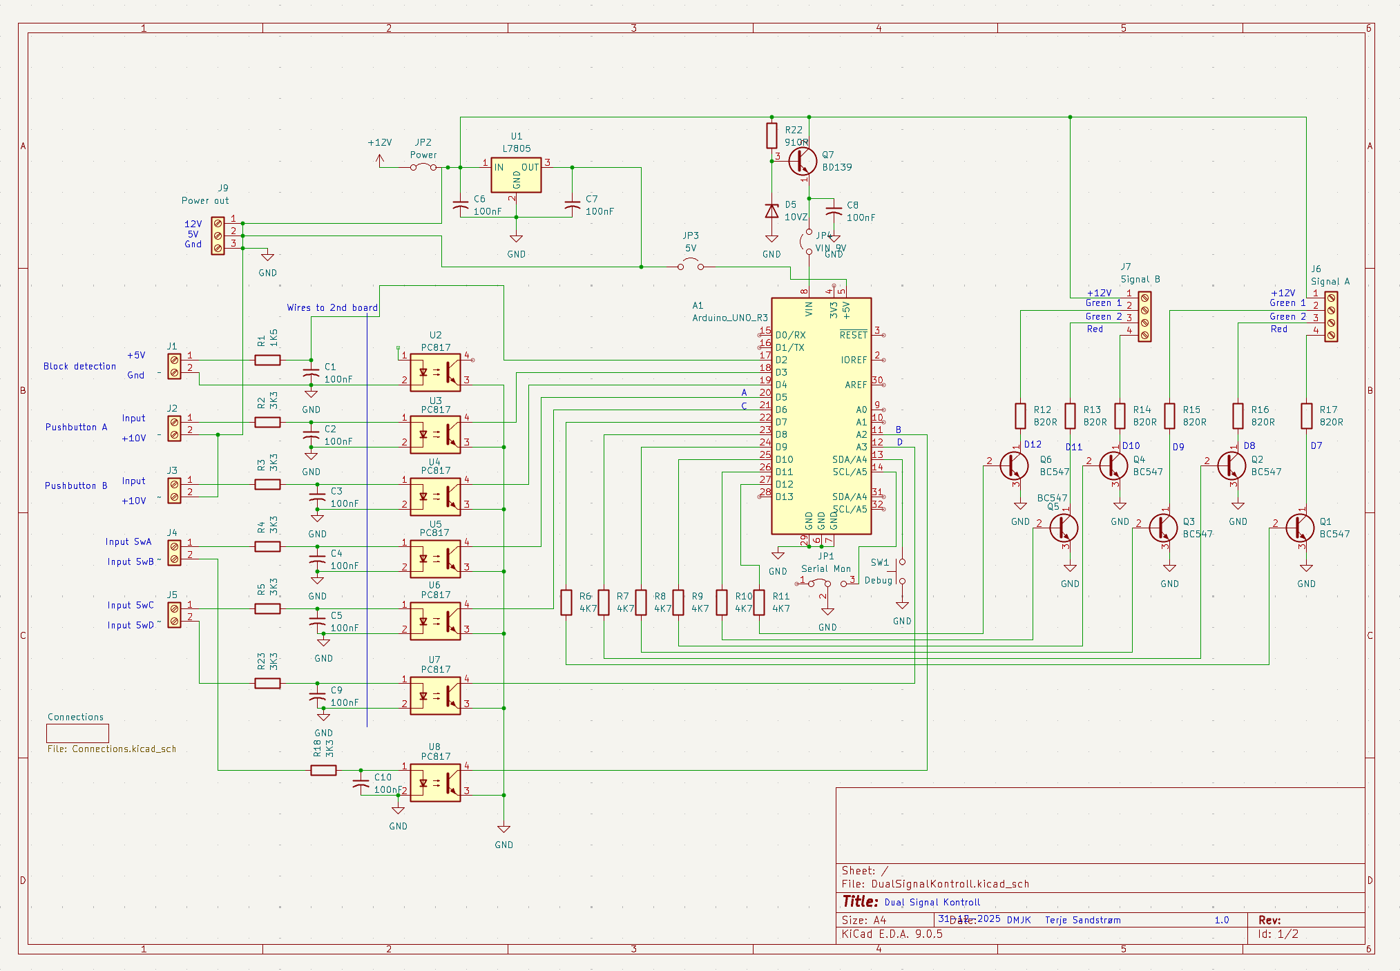
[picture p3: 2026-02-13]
DualSignalShield.png

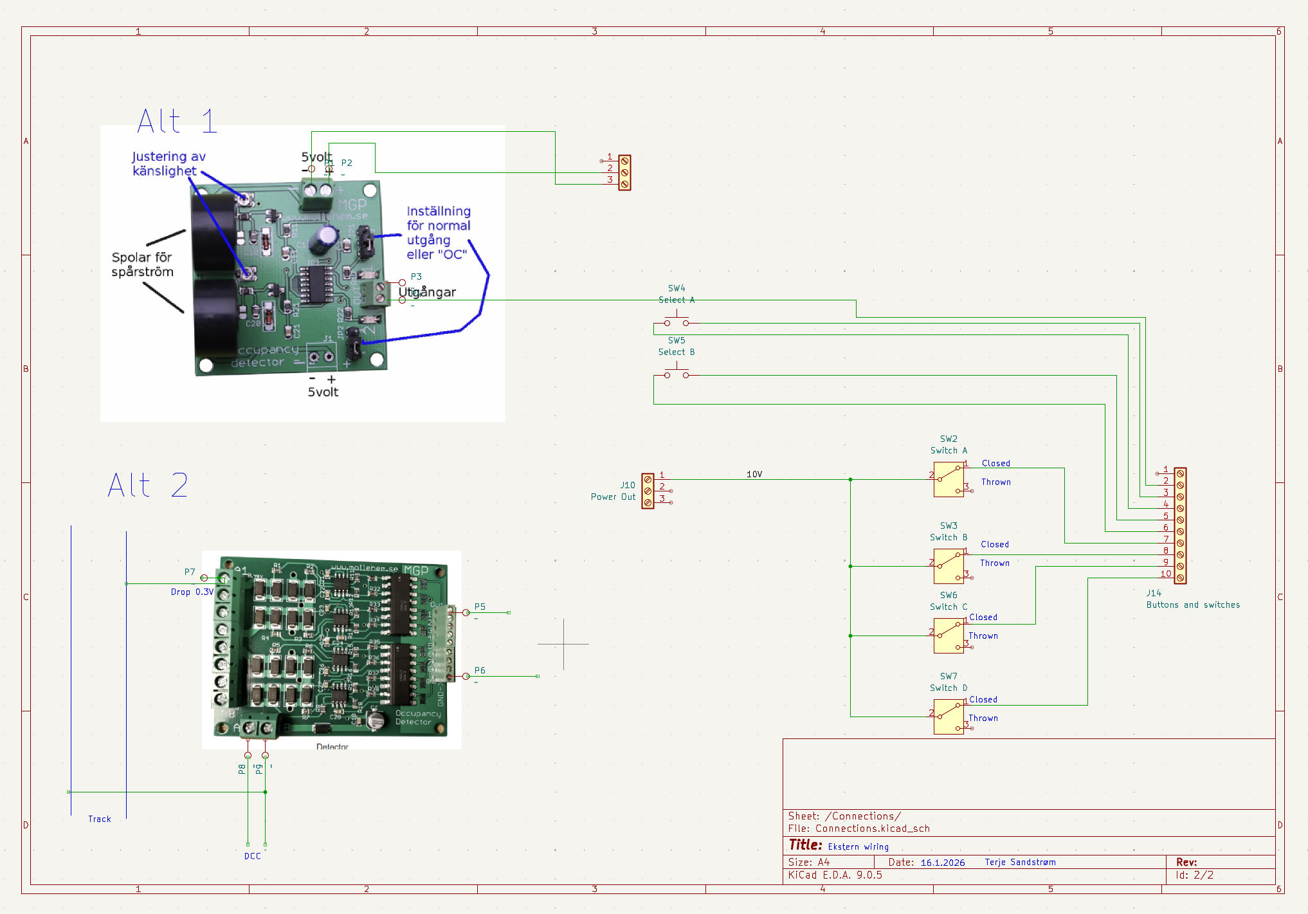
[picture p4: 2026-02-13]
Connections.png

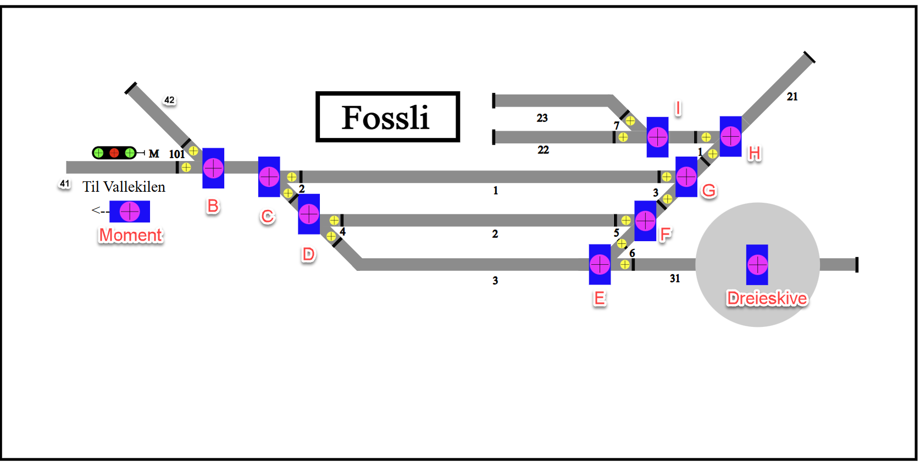
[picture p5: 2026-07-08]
PanelFossli.png

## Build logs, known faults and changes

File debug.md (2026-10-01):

# Debug log — Firmware boot I2C hang (2026-09-10)

## Symptom

After uploading `Firmware/Firmware.ino` to the bench Arduino (Uno-compatible,
ATmega328P, on COM3) and re-running the hardware-in-the-loop test:

```
dotnet test DrammenMJKConfig.IntegrationTests --filter "FullyQualifiedName~StatusSessionIntegrationTests"
```

all three tests reported:

```
No Arduino responded on any available COM port -- connect the board and retry.
```

`ArduinoTestHelper.Connect()` probes every COM port, opens it, waits for boot,
then expects `PING` -> `PONG` and `SI` -> `SITE 1`. Got nothing, on every port,
at every baud tried (115200 / 57600 / 9600), even after forcing a DTR/RTS
reset pulse manually.

## Diagnosis

1. Confirmed the upload itself was good: `arduino-cli upload --verify` reported
   `14008 bytes of flash verified`, device signature `1E 95 0F` (ATmega328P).
2. Confirmed the serial/USB path was healthy by flashing a **throwaway
   diagnostic sketch** (`Serial.begin(115200)` + print a banner + dump EEPROM)
   — it talked immediately. So the bootloader and UART were fine; the
   problem was specific to `Firmware.ino`'s own `setup()`.
3. The diagnostic sketch's EEPROM dump showed the board's EEPROM already held
   **valid, current-layout config** for this firmware: `BoardVAddr[0..1] =
   0x20, 0x21` (two signal boards), plus matching IODIR/GPPU, signal-lamp,
   inverter-enable and one switch slot — consistent with the
   `01d2608 Oppdatert med 2nd kort, Fossli Venstre` commit. Not stale data
   from the old firmware layout.
4. `Firmware.ino`'s `setup()` calls `apply_all_board_hw()`, which does
   `Wire.beginTransmission()/endTransmission()` to every board vaddr found in
   that EEPROM table (0x20 and 0x21 here) **before** printing its boot banner
   or entering the command loop.
5. The classic AVR `Wire` library has **no timeout** on its internal
   `while (!(TWCR & _BV(TWINT)))` waits. If the I2C bus never reaches the
   expected state — no pull-ups so SDA/SCL never rise, a device not present,
   or a device holding the clock low — `endTransmission()` spins forever.
   With two boards declared and no I2C hardware actually answering on the
   bench bus at the time, `setup()` hung on the very first transaction and
   never returned, so the firmware never printed anything and never answered
   `PING`.

This explains all three symptoms at once: avrdude (bootloader-only, no I2C)
worked, the throwaway sketch (no I2C) worked, and `Firmware.ino` (I2C at
boot, non-empty board table) hung.

## Fix

`Firmware/Firmware.ino`, `setup()` — one line after `Wire.begin()`:

```cpp
Wire.begin();
// Bound every TWI wait: without this the AVR Wire lib spins forever on a
// bus fault (no pull-ups / no device / SDA or SCL stuck low), so a single
// configured-but-absent board would hang the whole firmware here at boot,
// before the command loop ever runs. On timeout endTransmission() returns
// non-zero, which mcp_*_reg() already reports as "not OK" and
// apply_board_hw() already tolerates -- bring-up just skips the missing board.
Wire.setWireTimeout(3000 /* us */, true /* reset TWI HW on timeout */);
apply_all_board_hw();
```

`Wire.setWireTimeout()` is available in the installed `arduino:avr` core
(1.8.7). `mcp_write_reg()`/`mcp_read_reg()` already treat a non-zero
`endTransmission()` return as "not OK", and `apply_board_hw()` already
ignores that per-board failure — so a timed-out board is simply skipped
instead of hanging everything downstream. EEPROM config was not touched.

Verified after re-flash: boots and answers immediately —

```
!LysKontroll Firmware Phase 1
!Commands: PING SI ER EW EC MDIR MPU MW MR MRR MPOLL MBIT HWU HWD SW SR SCU SCD RST
PING -> PONG
SI   -> SITE 1
```

## Side fix found by the same test run

`DrammenMJKConfig.IntegrationTests/StatusSessionIntegrationTests.cs`,
`SystemConfigDownload_ReturnsWellFormedLines`: the line-tag regex was
`^[SPDLF] `, but `Firmware.ino`'s `cmdSCD()` also emits `G` (signal lamp
group), `V` (inverter-enable) and `T` (track detection) lines — tags added
to the protocol after this test's regex was written. The board's own `G 21
04 02 00` line (signal config for vaddr 0x21) is what exposed it. Widened to
`^[SPDLGVT] `.

Result: `StatusSessionIntegrationTests` 3/3 pass, `DrammenMJKConfig.Tests`
51/51 pass.

## Bus-check tooling (already exists)

No need to add anything to re-check the I2C bus — `DrammenMJKConfig`
already has it:

**Config mode (`C`) -> `B` "Bench test" -> `W` "Sweep 0x20-0x27"**
(or `P` "Probe a chip" for one address). On this Phase-1 wiring (bus 0, no
mux) the virtual address you type *is* the real I2C address, so enter `20`,
`21`. Before the `setWireTimeout` fix this sweep would have hung the
firmware the same way boot did (it calls `MR`, which hits the same
`endTransmission()`); now a missing address returns "no response" in ~3 ms.

Not yet built (proposed, not done — ask if wanted):
- a firmware `I2C`/`SCAN` command that address-probes `0x20`-`0x27` and
  replies with one line (e.g. `I2C 20 21`) instead of the PC looping `MR`
  eight times;
- an automatic scan at boot, logged as a `!I2C: 20 21` / `!I2C: none` status
  line, so every connect reports bus state without a manual sweep.

## Open question — external board's "command received" LED

Observation: the external signal board has an LED that stays on until it has
received a command from the Arduino, and it was observed **off** even while
the firmware was (at the time) hanging at boot with no I2C reaching it.
Flagged as strange, possibly a broken/misremembered LED.

Reasoning on why "LED off" doesn't actually prove the bus was alive during
the hang:
- A true "bus never reaches a valid state" hang (no pull-ups, SDA/SCL never
  rise) means the MCP never saw a valid START or any clocked bits at all —
  LED should stay **on** in that case. LED being off argues against that
  being the *whole* story.
- More likely explanation: the LED reflects an **earlier successful
  session**. The EEPROM already holds real config for 0x20/0x21 from the
  "2nd kort, Fossli Venstre" work, which could only have been written by
  Motor/Signal Scan talking to those chips over I2C successfully at some
  point. If the board latches "command received -> LED off" until it loses
  power, the LED is just showing that old state, not anything from the
  hung boot.
- Also possible: the bus/chips are fine and the hang was transient (a chip
  clock-stretching / holding SCL low, a marginal pull-up, or the boards
  briefly unpowered while reflashing) — a hung slave produces the same
  infinite `TWINT` wait as missing pull-ups, not just missing hardware.
- Or the LED is simply dead / wired other than remembered.

**Not resolved yet.** Next step: run the Bench-test sweep now that it can't
hang the firmware, and read that as ground truth over the LED:
- `0x20`/`0x21` ACK -> bus and chips are genuinely fine; the boot hang was
  transient and `setWireTimeout` is now just the safety net.
- nothing ACKs -> real bus/wiring fault. Check in order: I2C pull-ups
  (4.7k(ohm) SDA/SCL -> +5V; the Uno's internal ~20-50k(ohm) are often too
  weak for a ribbon cable), GND continuity Uno<->board, A4=SDA/A5=SCL
  wiring, the MCP23017 address-strap pins (A0-A2) actually matching
  0x20/0x21, and that the external board has power.

## Reference

- `arduino-cli` is not on PATH; use the copy bundled with Arduino IDE:
  `C:\Users\TerjeSandstrom\AppData\Local\Programs\Arduino IDE\resources\app\lib\backend\resources\arduino-cli.exe`
  (v1.5.1, `arduino:avr` core 1.8.7).
- Board FQBN: `arduino:avr:uno` (clone reports as "Unknown" to `board list`,
  must be given explicitly).
- Compile: `arduino-cli compile --fqbn arduino:avr:uno ./Firmware`
- Flash (verified): `arduino-cli upload -p COM3 --fqbn arduino:avr:uno --verify ./Firmware`
  (default upload is no-verify; add `--verbose` to see avrdude's own output).
- Run the config tool: `cd DrammenMJKConfig/DrammenMJKConfig && dotnet run`
  (auto-probes COM ports with the same `PING`/`SI` handshake as the
  integration test).

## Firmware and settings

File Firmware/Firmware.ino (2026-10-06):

// Firmware.ino — LysKontroll Phase 1 (FSCB/FCSBR over direct I2C)
//
// Copied from Simulator.ino and trimmed of all simulated-Pens business logic
// per PLAN_Phase1.md. Transport plumbing (readLine/dispatch/OK/ERR/status)
// and the EEPROM primitive commands (PING/SI/ER/EW/EC/RST) are unchanged in
// spirit from the simulator; everything else is new.
//
// No compiled-in board topology: the board hardware table (direction/pullup
// per MCP23017 chip) and the switch table (which motor bit is which switch)
// are both EEPROM-backed and populated entirely from the PC side (hardware.json
// via HWU, SystemConfig.json via SCU / Motor Scan). See PLAN_Phase1.md for the
// full design and reasoning.
//
// Protocol (115200 baud, line-based):
//   C# -> Arduino : "CMD [args]\n"
//   Arduino -> C# : response line(s)
//   Lines starting with '!' = status messages, always displayed by C# immediately.
//   All other lines = protocol responses, queued in C# capture mode.

#include <EEPROM.h>
#include <Wire.h>
#include <avr/pgmspace.h>
#include <avr/wdt.h>

// Defined here, ahead of everything else, because the Arduino build's
// auto-generated function prototypes are inserted right after the last
// #include — any function whose signature names one of these types must
// have the type already visible at that point, not just before its own body.
struct VAddrResolved { uint8_t bus; uint8_t realAddr; bool ok; };
struct SwitchRec {
    uint8_t motorVAddr, motorBit, polarity, fbVAddr, fbRettBit, fbAvvikBit;
    bool configured;
};
enum SwitchState : uint8_t { SW_RETT, SW_AVVIK, SW_BETWEEN, SW_FAULT };

// ---------------------------------------------------------------------------
// EEPROM layout (new — unrelated to the older Pens-letter Region1-6 layout)
// ---------------------------------------------------------------------------
#define EEPROM_MAGIC_ADDR   0x01
#define EEPROM_MAGIC_VALUE  0xA5

// Fixed board fact: dreieskive motor side (declared, not scanned). There is
// exactly one dreieskive for the whole site (FCSBR only) -- unlike the status
// LED below, this stays a single slot, not one per board.
#define ADDR_DREI_VADDR     0x02
#define ADDR_DREI_PINBASE   0x03
#define ADDR_DREI_CWPOL     0x04

// Test/Prod mode gate. 'P' = prod: boots exactly like before this existed --
// Wire.begin() and apply_all_board_hw() fire immediately at startup. Anything
// else -- including a blank/erased EEPROM byte (0xFF), or 'T' explicitly --
// is test mode, the default: the TWI peripheral is never touched and SDA/SCL
// stay plain pulled-up GPIO inputs, so bench diagnostics (I2CD, and probing
// with a wire by hand) can safely characterize a new install's wiring before
// anything is allowed to actually drive the bus. See cmdSETMODE. Shorting
// SDA/SCL to GND is always electrically safe on this hardware regardless of
// mode -- I2C is open-drain by design (the TWI peripheral only ever pulls
// low, never drives push-pull high) and I2CD only ever configures these pins
// as inputs -- but the mode gate exists anyway so an install with a genuine
// wiring fault gets caught by input-only probing first, deliberately, before
// firmware ever tries to talk to a board over a cable run that hasn't been
// verified yet.
#define ADDR_MODE            0x05
#define MODE_PROD            ((uint8_t)'P')

// 0x07-0x0B previously held digital-fade timing (fadeMs/fadeSteps/pwmPeriodUs)
// for the software-PWM signal-lamp fade loop -- removed, signal fading is
// analog on the board now, not something firmware ever needs to drive.
// Left unused rather than reclaimed, no reason to renumber everything below.

// Switch table — 32-slot capacity
#define SWITCH_CAP           32
#define REGION_SLOT_MVADDR  0x10   // SlotMotorVAddr[32]
#define REGION_SLOT_MBIT    0x30   // SlotMotorBit[32]
#define REGION_SLOT_POL     0x50   // SlotPolarity[32]
#define REGION_SLOT_FBRETT  0x70   // SlotFeedbackRettBit[32]
#define REGION_SLOT_FBAVVIK 0x90   // SlotFeedbackAvvikBit[32]
#define REGION_SLOT_FVADDR  0x100  // SlotFeedbackVAddr[32]

// Board hardware table — 16-slot capacity
#define BOARD_CAP            16
#define REGION_BOARD_VADDR  0xB0   // BoardVAddr[16]
#define REGION_BOARD_IODIRA 0xC0   // BoardIodirA[16]
#define REGION_BOARD_IODIRB 0xD0   // BoardIodirB[16]
#define REGION_BOARD_GPPUA  0xE0   // BoardGppuA[16]
#define REGION_BOARD_GPPUB  0xF0   // BoardGppuB[16]

// SVB switch table — 32-slot capacity (unpopulated in Phase 1, no SVB present)
#define SVBSW_CAP            32
#define REGION_SVBSW_VADDR   0x120 // SvbSwVAddr[32]
#define REGION_SVBSW_BITPRI  0x140 // SvbSwBitPrimary[32]
#define REGION_SVBSW_BITSEC  0x160 // SvbSwBitSecondary[32]
#define REGION_SVBSW_KIND    0x180 // SvbSwKind[32]: 0 = pens, 1 = dreieskive (bitPri CW, bitSec CCW), 2 = green request button
#define REGION_SVBSW_TGTSLOT 0x1A0 // SvbSwTargetSlot[32]

// Status LED — one per board, indexed by the SAME slot the board hardware
// table (REGION_BOARD_*) assigns that board's vaddr (via board_find_slot()).
// Was a single slot (0x05/0x06) until FCSBL showed up with its own status
// LED distinct from FCSBR's. No separate VAddr array needed -- the vaddr for
// slot N is already BoardVAddr[N]; storing it again here would just be a
// duplicate of that value.
#define REGION_LED_BIT       0x1C0 // StatusLedBit[BOARD_CAP] -- 0xFF = no LED for this board slot

// Signal lamp group — 3 bits (Red/Green1/Green2) per board, same board-slot
// indexing as the status LED above (via board_find_slot()). 0xFF in
// SignalRed = no signal for this board slot (Green1/Green2 unused then).
#define REGION_SIGNAL_RED    0x1D0 // SignalRedBit[BOARD_CAP]
#define REGION_SIGNAL_GREEN1 0x1E0 // SignalGreen1Bit[BOARD_CAP]
#define REGION_SIGNAL_GREEN2 0x1F0 // SignalGreen2Bit[BOARD_CAP]

// Inverter enable — some one-bit-drive boards need an external inverter
// (the one that produces the H-bridge's second line from a single MCU bit)
// actively enabled after bring-up, unlike the always-on inverter variant.
// Per board-slot, same board_find_slot() indexing as above. Port: 0=A, 1=B
// (matches MDIR/MW's isB convention elsewhere in this file). 0xFF in Port =
// no inverter-enable pin for this board slot.
#define REGION_INVENA_PORT   0x200 // InverterEnablePort[BOARD_CAP]
#define REGION_INVENA_BIT    0x210 // InverterEnableBit[BOARD_CAP]

// Track detection — one input bit per board-slot (is a train present).
// ActiveHigh: 1 = high means train present, 0 = low means train present,
// 0xFF = unset. 0xFF in Bit = no track detection for this board slot.
#define REGION_TRACK_BIT       0x220 // TrackDetectBit[BOARD_CAP]
#define REGION_TRACK_ACTIVEHI  0x230 // TrackDetectActiveHigh[BOARD_CAP]

// SVB panel switch extras (appended after the original layout, so nothing
// above moved): which port the input bit(s) are on, and which input level
// means the panel switch is at Rett (pens only).
#define REGION_SVBSW_PORT    0x240 // SvbSwPort[32]: 0 = A, 1 = B
#define REGION_SVBSW_POL     0x260 // SvbSwPolarity[32]: input level for Rett

// SVB panel LEDs -- one entry per LED. Target is a switch-table slot (pens)
// or 0xFF for the panel's signal lamp. Role: 0 = Rett, 1 = Avvik (pens),
// 2 = Red, 3 = Green1, 4 = Green2 (signal). 0xFF in VAddr = unused entry.
// Stored only; the runtime that lights them from feedback comes later.
#define PLED_CAP             48
#define REGION_PLED_VADDR    0x280 // PanelLedVAddr[48]
#define REGION_PLED_PORTBIT  0x2B0 // PanelLedPortBit[48]: bit | (isB << 3)
#define REGION_PLED_TARGET   0x2E0 // PanelLedTarget[48]
#define REGION_PLED_ROLE     0x310 // PanelLedRole[48]

#define EEPROM_ERASE_END     0x33F // EC clears 0x02..0x33F plus the magic byte

// ---------------------------------------------------------------------------
// MCP23017 register addresses
// ---------------------------------------------------------------------------
#define MCP_IODIRA 0x00
#define MCP_IODIRB 0x01
#define MCP_GPPUA  0x0C
#define MCP_GPPUB  0x0D
#define MCP_GPIOA  0x12
#define MCP_GPIOB  0x13
#define MCP_OLATA  0x14
#define MCP_OLATB  0x15

// ---------------------------------------------------------------------------
// Helpers (unchanged in shape from Simulator.ino)
// ---------------------------------------------------------------------------
static void ok()    { Serial.println(F("OK")); }

static void errCmd(const __FlashStringHelper* msg) {
    Serial.print(F("ERR "));
    Serial.println(msg);
}

static void status(const __FlashStringHelper* msg) {
    Serial.print('!');
    Serial.println(msg);
}

static void softReset() {
    status(F("Resetting..."));
    delay(100);
    wdt_enable(WDTO_15MS);
    while (true) {}
}

// Read one line from Serial (blocking, respects setTimeout).
// Strips trailing \r\n. Returns true if any bytes were read.
static bool readLine(char* buf, uint8_t maxLen) {
    uint8_t n = Serial.readBytesUntil('\n', buf, maxLen - 1);
    buf[n] = '\0';
    if (n > 0 && buf[n - 1] == '\r') buf[--n] = '\0';
    return n > 0;
}

static bool parseHex(const char* s, uint16_t* out) {
    if (!s || !*s) return false;
    uint16_t v = 0;
    while (*s) {
        char c = *s++;
        if      (c >= '0' && c <= '9') v = (uint16_t)(v * 16 + (c - '0'));
        else if (c >= 'A' && c <= 'F') v = (uint16_t)(v * 16 + (c - 'A' + 10));
        else if (c >= 'a' && c <= 'f') v = (uint16_t)(v * 16 + (c - 'a' + 10));
        else return false;
    }
    *out = v;
    return true;
}

static bool parseUint(const char* s, uint16_t* out) {
    if (!s || !*s) return false;
    uint16_t v = 0;
    while (*s) {
        char c = *s++;
        if (c < '0' || c > '9') return false;
        v = (uint16_t)(v * 10 + (c - '0'));
    }
    *out = v;
    return true;
}

// Port token is exactly "A" or "B".
static bool parsePort(const char* s, uint8_t* isPortB) {
    if (!s || (s[0] != 'A' && s[0] != 'B') || s[1] != '\0') return false;
    *isPortB = (s[0] == 'B') ? 1 : 0;
    return true;
}

// ---------------------------------------------------------------------------
// Virtual-address resolver — bus lives here, and only here.
// vaddr = bus*0x10 + real_i2c_address (real address always 0x20-0x27)
// ---------------------------------------------------------------------------
// Valid range: buses 0-3 (vaddr 0x20-0x57), real address 0x20-0x27 only.
static VAddrResolved resolve_vaddr(uint8_t vaddr) {
    VAddrResolved r;
    r.bus      = (uint8_t)((vaddr >> 4) - 2);
    r.realAddr = 0x20 | (vaddr & 0x0F);
    r.ok       = vaddr >= 0x20 && vaddr <= 0x57 && (vaddr & 0x0F) <= 7;
    return r;
}

// I2C mux (TCA9548A/PCA9548A/PCA9546A family -- all take one control byte,
// bit n = channel n enabled). Address 0x70 = all address pins low.
// ponytail: chip/address assumed, not yet stated in the plans -- change here.
#define MUX_ADDR 0x70

// Selects the bus via the mux, then the caller addresses the real chip.
// The mux's ACK is deliberately ignored: on the bench there is no mux, the
// select write just goes unanswered, and every chip sits directly on the
// one physical bus -- so the same virtual addresses work with or without
// the mux fitted, and only the real address matters on the bench.
static bool i2c_select_bus(uint8_t bus) {
    Wire.beginTransmission(MUX_ADDR);
    Wire.write((uint8_t)(1 << bus));
    Wire.endTransmission();
    return true;
}

// Set once in setup() from EEPROM (ADDR_MODE) and never touched again this
// boot. Every actual I2C transaction funnels through the two primitives
// below, so gating here is the single choke point -- test mode means
// literally nothing ever calls Wire.beginTransmission(), not just "the
// board table is empty".
static bool g_prodMode = false;

// ---------------------------------------------------------------------------
// Generic MCP23017 driver — 2 primitives, reused unchanged by every board.
// ---------------------------------------------------------------------------
static void mcp_write_reg(uint8_t vaddr, uint8_t reg, uint8_t val, bool* okOut) {
    if (!g_prodMode) { if (okOut) *okOut = false; return; }
    VAddrResolved r = resolve_vaddr(vaddr);
    if (!r.ok || !i2c_select_bus(r.bus)) { if (okOut) *okOut = false; return; }
    Wire.beginTransmission(r.realAddr);
    Wire.write(reg);
    Wire.write(val);
    uint8_t err = Wire.endTransmission();
    if (okOut) *okOut = (err == 0);
}

static uint8_t mcp_read_reg(uint8_t vaddr, uint8_t reg, bool* okOut) {
    if (!g_prodMode) { if (okOut) *okOut = false; return 0xFF; }
    VAddrResolved r = resolve_vaddr(vaddr);
    if (!r.ok || !i2c_select_bus(r.bus)) { if (okOut) *okOut = false; return 0xFF; }
    Wire.beginTransmission(r.realAddr);
    Wire.write(reg);
    uint8_t err = Wire.endTransmission(false);
    if (err != 0) { if (okOut) *okOut = false; return 0xFF; }
    Wire.requestFrom((int)r.realAddr, 1);
    if (!Wire.available()) { if (okOut) *okOut = false; return 0xFF; }
    uint8_t v = Wire.read();
    if (okOut) *okOut = true;
    return v;
}

// ---------------------------------------------------------------------------
// Board hardware table — data-driven boot-time bring-up, no compiled board topology.
// ---------------------------------------------------------------------------
static bool board_find_slot(uint8_t vaddr, uint8_t* slotOut) {
    for (uint8_t i = 0; i < BOARD_CAP; i++) {
        if (EEPROM.read(REGION_BOARD_VADDR + i) == vaddr) { *slotOut = i; return true; }
    }
    return false;
}

static bool board_alloc_slot(uint8_t* slotOut) {
    for (uint8_t i = 0; i < BOARD_CAP; i++) {
        if (EEPROM.read(REGION_BOARD_VADDR + i) == 0xFF) { *slotOut = i; return true; }
    }
    return false;
}

static void apply_board_hw(uint8_t slot) {
    uint8_t vaddr = EEPROM.read(REGION_BOARD_VADDR + slot);
    if (vaddr == 0xFF) return;
    uint8_t iodirA = EEPROM.read(REGION_BOARD_IODIRA + slot);
    uint8_t iodirB = EEPROM.read(REGION_BOARD_IODIRB + slot);
    uint8_t gppuA  = EEPROM.read(REGION_BOARD_GPPUA  + slot);
    uint8_t gppuB  = EEPROM.read(REGION_BOARD_GPPUB  + slot);
    bool okFlag;
    mcp_write_reg(vaddr, MCP_IODIRA, iodirA, &okFlag);
    mcp_write_reg(vaddr, MCP_IODIRB, iodirB, &okFlag);
    mcp_write_reg(vaddr, MCP_GPPUA,  gppuA,  &okFlag);
    mcp_write_reg(vaddr, MCP_GPPUB,  gppuB,  &okFlag);
    mcp_write_reg(vaddr, MCP_OLATA,  0x00,   &okFlag); // universal safe default
    mcp_write_reg(vaddr, MCP_OLATB,  0x00,   &okFlag); // (see PLAN_Phase1.md)

    // Inverter-enable pins (some one-bit-drive boards need an external
    // inverter actively enabled after bring-up, see PLAN_Phase3.md, "Motor
    // drive") are just a plain hardware.json 'out' declaration now, applied
    // by the IODIRA/IODIRB writes above like any other output -- no special
    // deferred flip. An earlier version flipped this pin's direction only
    // AFTER the OLATA/OLATB=0x00 safe-default writes, to guarantee it never
    // started driving before the motor bits were confirmed zeroed. Dropped
    // deliberately (site owner's call): the pin is wired so the motor's two
    // terminals are always hardware-complementary (this bit direct to one
    // terminal, inverted to the other) -- the only possible effect of a
    // stale OLAT bit surviving from a prior session is a reversed-direction
    // pulse lasting a single I2C register write (tens of microseconds), far
    // too short to produce any mechanical movement on a multi-second switch
    // throw, and never a same-state short since the terminals can't match
    // while the inverter is live. REGION_INVENA_PORT/BIT (SCU/SCD 'V') still
    // exists purely for SystemConfig.json backup/restore visibility -- no
    // longer consulted here.
}

static void apply_all_board_hw() {
    for (uint8_t i = 0; i < BOARD_CAP; i++) apply_board_hw(i);
}

// ---------------------------------------------------------------------------
// Switch table — resolve_switch() is the one function both SW/SR and the
// (future, Phase 2+) autonomous runtime loop will call.
// ---------------------------------------------------------------------------
static SwitchRec resolve_switch(uint8_t slot) {
    SwitchRec r;
    r.motorVAddr = EEPROM.read(REGION_SLOT_MVADDR + slot);
    r.configured = (r.motorVAddr != 0xFF);
    if (!r.configured) return r;
    r.motorBit   = EEPROM.read(REGION_SLOT_MBIT    + slot);
    r.polarity   = EEPROM.read(REGION_SLOT_POL     + slot);
    r.fbVAddr    = EEPROM.read(REGION_SLOT_FVADDR  + slot);
    r.fbRettBit  = EEPROM.read(REGION_SLOT_FBRETT  + slot);
    r.fbAvvikBit = EEPROM.read(REGION_SLOT_FBAVVIK + slot);
    return r;
}

static SwitchState read_switch_state(const SwitchRec& r, bool* okOut) {
    uint8_t v = mcp_read_reg(r.fbVAddr, MCP_GPIOA, okOut);
    if (!*okOut) return SW_FAULT;
    uint8_t rettVal  = (v >> r.fbRettBit)  & 1;
    uint8_t avvikVal = (v >> r.fbAvvikBit) & 1;
    if (rettVal && !avvikVal) return SW_RETT;
    if (!rettVal && avvikVal) return SW_AVVIK;
    if (rettVal && avvikVal)  return SW_BETWEEN;
    return SW_FAULT;
}

static const __FlashStringHelper* switchStateName(SwitchState s) {
    switch (s) {
        case SW_RETT:    return F("RETT");
        case SW_AVVIK:   return F("AVVIK");
        case SW_BETWEEN: return F("BETWEEN");
        default:         return F("FAULT");
    }
}

// ---------------------------------------------------------------------------
// Command handlers
// (strtok state is live on entry -- use strtok(nullptr, " ") for next token)
// ---------------------------------------------------------------------------

static void cmdPing() { Serial.println(F("PONG")); }

static void cmdSI() {
    Serial.print(F("SITE 1 MODE "));
    Serial.println((char)(g_prodMode ? 'P' : 'T'));
}

// Test/Prod mode gate ("SETMODE T"/"SETMODE P") -- see ADDR_MODE above for
// the full reasoning. Only writes the stored EEPROM byte; g_prodMode (and
// therefore whether Wire.begin()/apply_all_board_hw() ran) is only ever set
// in setup(), so a mode change needs a reset (RST) to actually take effect
// -- deliberately, so switching modes can never interrupt a bring-up
// sequence or a switch mid-throw.
static void cmdSETMODE() {
    char* arg = strtok(nullptr, " ");
    if (!arg || arg[1] != '\0' || (arg[0] != 'T' && arg[0] != 'P')) { errCmd(F("bad mode -- use T or P")); return; }
    EEPROM.update(ADDR_MODE, arg[0] == 'P' ? MODE_PROD : (uint8_t)'T');
    ok();
}

static void cmdER() {
    uint16_t addr;
    if (!parseHex(strtok(nullptr, " "), &addr)) { errCmd(F("bad addr")); return; }
    char buf[3];
    snprintf(buf, sizeof(buf), "%02X", EEPROM.read(addr));
    Serial.println(buf);
}

static void cmdEW() {
    uint16_t addr, val;
    if (!parseHex(strtok(nullptr, " "), &addr)) { errCmd(F("bad addr")); return; }
    if (!parseHex(strtok(nullptr, " "), &val))  { errCmd(F("bad val"));  return; }
    EEPROM.update(addr, (uint8_t)val);
    ok();
}

static void cmdEC() {
    for (uint16_t a = 0x02; a <= EEPROM_ERASE_END; a++) EEPROM.update(a, 0xFF);
    EEPROM.update(EEPROM_MAGIC_ADDR, 0xFF);
    ok();
}

// ---- Raw discovery primitives (Motor Scan / bench debug only) -------------

static void cmdMDIR() {
    uint16_t vaddr, mask; uint8_t isB;
    if (!parseHex(strtok(nullptr, " "), &vaddr)) { errCmd(F("bad vaddr")); return; }
    if (!parsePort(strtok(nullptr, " "), &isB))  { errCmd(F("bad port"));  return; }
    if (!parseHex(strtok(nullptr, " "), &mask))  { errCmd(F("bad mask"));  return; }
    bool okFlag;
    mcp_write_reg((uint8_t)vaddr, isB ? MCP_IODIRB : MCP_IODIRA, (uint8_t)mask, &okFlag);
    if (okFlag) ok(); else errCmd(F("i2c"));
}

static void cmdMPU() {
    uint16_t vaddr, mask; uint8_t isB;
    if (!parseHex(strtok(nullptr, " "), &vaddr)) { errCmd(F("bad vaddr")); return; }
    if (!parsePort(strtok(nullptr, " "), &isB))  { errCmd(F("bad port"));  return; }
    if (!parseHex(strtok(nullptr, " "), &mask))  { errCmd(F("bad mask"));  return; }
    bool okFlag;
    mcp_write_reg((uint8_t)vaddr, isB ? MCP_GPPUB : MCP_GPPUA, (uint8_t)mask, &okFlag);
    if (okFlag) ok(); else errCmd(F("i2c"));
}

static void cmdMW() {
    uint16_t vaddr, val; uint8_t isB;
    if (!parseHex(strtok(nullptr, " "), &vaddr)) { errCmd(F("bad vaddr")); return; }
    if (!parsePort(strtok(nullptr, " "), &isB))  { errCmd(F("bad port"));  return; }
    if (!parseHex(strtok(nullptr, " "), &val))   { errCmd(F("bad val"));   return; }
    bool okFlag;
    mcp_write_reg((uint8_t)vaddr, isB ? MCP_OLATB : MCP_OLATA, (uint8_t)val, &okFlag);
    if (okFlag) ok(); else errCmd(F("i2c"));
}

static void cmdMR() {
    uint16_t vaddr; uint8_t isB;
    if (!parseHex(strtok(nullptr, " "), &vaddr)) { errCmd(F("bad vaddr")); return; }
    if (!parsePort(strtok(nullptr, " "), &isB))  { errCmd(F("bad port"));  return; }
    bool okFlag;
    uint8_t v = mcp_read_reg((uint8_t)vaddr, isB ? MCP_GPIOB : MCP_GPIOA, &okFlag);
    if (!okFlag) { errCmd(F("i2c")); return; }
    char buf[3];
    snprintf(buf, sizeof(buf), "%02X", v);
    Serial.println(buf);
}

// Generic MCP register read -- "MRR <vaddr> <reg>", reg in hex. A raw
// diagnostic for bring-up: lets the PC read IODIR/OLAT/GPPU directly to
// verify a pin's actual configured direction and latch, not just its
// live level (MR / GPIO).
static void cmdMRR() {
    uint16_t vaddr, reg;
    if (!parseHex(strtok(nullptr, " "), &vaddr)) { errCmd(F("bad vaddr")); return; }
    if (!parseHex(strtok(nullptr, " "), &reg))   { errCmd(F("bad reg"));   return; }
    bool okFlag;
    uint8_t v = mcp_read_reg((uint8_t)vaddr, (uint8_t)reg, &okFlag);
    if (!okFlag) { errCmd(F("i2c")); return; }
    char buf[3];
    snprintf(buf, sizeof(buf), "%02X", v);
    Serial.println(buf);
}
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
void loop() {
    char line[48];
    if (!readLine(line, sizeof(line))) return;
    dispatch(line);
}

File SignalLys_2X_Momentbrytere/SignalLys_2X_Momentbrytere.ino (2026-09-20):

#include <EEPROM.h>

// Uncomment to enable serial monitor output
#define SERIAL_MONITOR_ENABLED
#define DEBUG_MSG

enum Direction {
  DIR_NONE = 0,
  DIR_A_TO_B = 1,
  DIR_B_TO_A = 2
};

struct Pins {
  // Inputs (active-low)
  static const uint8_t Train = 2;
  static const uint8_t PBA = 3;  // Pushbutton A
  static const uint8_t PBB = 4;  // Pushbutton B
  static const uint8_t SCA = 5;  // Switch A closed
  static const uint8_t SCB = A2; // Switch B closed
  static const uint8_t SCC = 6;  // Switch C closed
  static const uint8_t SCD = A3; // Switch D closed
  static const uint8_t Debug = A4;
  static const uint8_t SerialEnable = A5;

  // Outputs – Signal A
  static const uint8_t A_R = 7;
  static const uint8_t A_G1 = 9;
  static const uint8_t A_G2 = 8;

  // Outputs – Signal B
  static const uint8_t B_R = 10;
  static const uint8_t B_G1 = 12;
  static const uint8_t B_G2 = 11;
};

class DebouncedActiveLow {
public:
  void Begin(uint8_t pin) {
    _pin = pin;
    _stable = ReadRaw();
    _lastStable = _stable;
    _changedAt = millis();
  }

  bool PressedEvent(uint32_t debounceMs, const char* debugName = nullptr) {
    bool raw = ReadRaw();
    if (raw != _stable) {
      _stable = raw;
      _changedAt = millis();
    }
    if ((millis() - _changedAt) < debounceMs) return false;

    bool now = _stable;
    bool was = _lastStable;

    // Only print when state actually changes (edge detection moment)
    if (now != was && debugName != nullptr) {
      Serial.print("EDGE DETECT ");
      Serial.print(debugName);
      Serial.print(": was=");
      Serial.print(was);
      Serial.print(" now=");
      Serial.print(now);
      Serial.print(" result=");
      Serial.println((was == true && now == false) ? "PRESS" : "release");
    }

    _lastStable = now;

    return (was == true && now == false);  // falling edge = press
  }

  bool IsActive(uint32_t debounceMs) {
    bool raw = ReadRaw();
    if (raw != _stable) {
      _stable = raw;
      _changedAt = millis();
    }
    if ((millis() - _changedAt) < debounceMs) return !raw;
    return !_stable;  // active-low
  }

private:
  bool ReadRaw() const {
    return digitalRead(_pin) == HIGH;
  }

  uint8_t _pin = 0;
  bool _stable = true;
  bool _lastStable = true;
  uint32_t _changedAt = 0;
};

// Debug states: 0=OFF, 1=ALL_ON, 2=CYCLE, 3=MAN_0, 4=MAN_1, 5=MAN_2, 6=MAN_3, 7=MAN_4, 8=MAN_5
static const uint8_t DBG_OFF = 0;
static const uint8_t DBG_ALL_ON = 1;
static const uint8_t DBG_CYCLE = 2;
static const uint8_t DBG_MAN_0 = 3;
static const uint8_t DBG_MAN_1 = 4;
static const uint8_t DBG_MAN_2 = 5;
static const uint8_t DBG_MAN_3 = 6;
static const uint8_t DBG_MAN_4 = 7;
static const uint8_t DBG_MAN_5 = 8;

static const int EepromAddrDirection = 0;

static Direction g_direction = DIR_NONE;  // Current direction state
static uint8_t g_dbgState = DBG_OFF;
static uint8_t g_cycleStep = 0;      // for CYCLE mode LED stepping
static uint32_t g_dbgLast = 0;
static uint8_t g_flashCount = 6;     // for exit flash sequence (6 = complete/not flashing)
static bool g_flashOn = false;

// Switch state tracking for change detection
static bool g_prevSCA = false;
static bool g_prevSCB = false;
static bool g_prevSCC = false;
static bool g_prevSCD = false;

// Train detection - IIR filter with hysteresis (Schmitt trigger) + delay
static int32_t g_trainAccum = 0;             // Accumulated "HIGH time" in ms
static uint32_t g_trainLastSample = 0;       // Last sample timestamp
static const int32_t TrainFilterMs = 20;     // Filter window ~20ms
static const int32_t TrainHighThresh = 12;   // 60% - must exceed to go HIGH
static const int32_t TrainLowThresh = 8;     // 40% - must drop below to go LOW
static bool g_trainFiltered = false;         // Filtered train state (after debounce)
static uint32_t g_trainDetectedAt = 0;       // When filtered state first went HIGH
static const uint32_t TrainDelayMs = 1000;   // 2 second delay before taking effect

static const uint32_t FadeMs      = 1000;
static const uint16_t PwmPeriodUs = 1000;
static const uint8_t  FadeSteps   = 60;

static DebouncedActiveLow g_btnA;
static DebouncedActiveLow g_btnB;
static DebouncedActiveLow g_swA;
static DebouncedActiveLow g_swB;
static DebouncedActiveLow g_swC;
static DebouncedActiveLow g_swD;
static DebouncedActiveLow g_btnDbg;


// EEPROM functions - kept for future use but not currently active
static void LoadDirection() {
  uint8_t val = EEPROM.read(EepromAddrDirection);
  if (val <= DIR_B_TO_A) {
    g_direction = static_cast<Direction>(val);
  } else {
    g_direction = DIR_NONE;
  }
}

static void SaveDirection() {
  EEPROM.update(EepromAddrDirection, static_cast<uint8_t>(g_direction));
}

static void ResetDirectionToKnown() {
  g_direction = DIR_NONE;
  EEPROM.update(EepromAddrDirection, DIR_NONE);
}

static void WriteLamp(uint8_t pin, bool on) {
  digitalWrite(pin, on ? HIGH : LOW);
}

static void SetAllLamps(bool on) {
  WriteLamp(Pins::A_R, on);
  WriteLamp(Pins::A_G1, on);
  WriteLamp(Pins::A_G2, on);
  WriteLamp(Pins::B_R, on);
  WriteLamp(Pins::B_G1, on);
  WriteLamp(Pins::B_G2, on);
}

static void SetOneLampByStep(uint8_t step) {
  SetAllLamps(false);
  switch (step % 6) {
    case 0: WriteLamp(Pins::A_G1, true); break;
    case 1: WriteLamp(Pins::A_G2, true); break;
    case 2: WriteLamp(Pins::A_R, true); break;
    case 3: WriteLamp(Pins::B_G1, true); break;
    case 4: WriteLamp(Pins::B_G2, true); break;
    default: WriteLamp(Pins::B_R, true); break;
  }
}

static void FadeGroup(uint8_t* pins, uint8_t count, bool fadeIn, uint32_t totalMs) {
  if (count == 0) return;
  uint32_t stepMs = totalMs / FadeSteps;
  for (uint8_t i = 0; i < FadeSteps; i++) {
    uint8_t duty = fadeIn
      ? (uint8_t)((uint32_t)i * 255 / (FadeSteps - 1))
      : (uint8_t)(255 - (uint32_t)i * 255 / (FadeSteps - 1));
    uint32_t deadline = millis() + stepMs;
    uint16_t highUs = (uint32_t)duty * PwmPeriodUs / 255;
    uint16_t lowUs  = PwmPeriodUs - highUs;
    while (millis() < deadline) {
      if (highUs > 0) {
        for (uint8_t j = 0; j < count; j++) digitalWrite(pins[j], HIGH);
        delayMicroseconds(highUs);
      }
      if (lowUs > 0) {
        for (uint8_t j = 0; j < count; j++) digitalWrite(pins[j], LOW);
        delayMicroseconds(lowUs);
      }
    }
  }
  for (uint8_t j = 0; j < count; j++)
    digitalWrite(pins[j], fadeIn ? HIGH : LOW);
}


static const uint8_t LampPins[6] = {
  Pins::A_R, Pins::A_G1, Pins::A_G2,
  Pins::B_R, Pins::B_G1, Pins::B_G2
};
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

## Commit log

2025-12-31 Code for arduino and schema for shield.
    [DualSignalKontroll.kicad_pcb, DualSignalKontroll.kicad_sch]
2025-12-31 Added EEPROM
    [DualSignalKontroll.kicad_sch]
2025-12-31 updated schema
    [DualSignalKontroll.kicad_sch]
2026-01-06 Updated schema and code
    [DualSignalKontroll.kicad_sch, untitled.kicad_sch]
2026-01-06 initial code
    [Connections.kicad_sch, DualSignalKontroll.kicad_sch, untitled.kicad_sch]
2026-01-13 Started on V2
    [Connections.kicad_sch, DualSignalKontroll.kicad_sch, untitled.kicad_sch]
2026-01-14 updated to new V2 code
    [DualSignalKontroll.kicad_sch, untitled.kicad_sch]
2026-01-14 Added switch C as another input
2026-02-13 Versjon med 4 penser
    [Connections.kicad_sch, DualSignalKontroll.kicad_sch]
2026-02-13 working with more debug info
    [Connections.kicad_sch, DualSignalKontroll.kicad_sch]
2026-05-14 IIR filter for debouncing train is added
2026-05-14 mixed hardware and software pwm
2026-05-14 fixing sequence of lamps correctly
    [SignalLys_2X_Momentbrytere.ino]
2026-08-14 Before rewrite for new boards
2026-09-10 Add bench bring-up pin/input test tooling; fix inverter-enable path
    Operate mode (CommandSession):
    - New "Motor Pin Test": explicit model of every output bit (inverter-enable
    + one per switch motor), rewrites all of them on each change, and reads
    the port(s) plus IODIR back so commanded-vs-measured and pin direction
    are visible. For wiring bring-up.
    - New "Input Test": reads IODIR back to find every input-configured pin,
    then polls GPIO ~3x/s and redraws one line in place; any key stops.
    - All the small numbered menus (board submenu, signals, status light) take
    a single keypress now instead of needing Enter.
    Firmware:
    - MBIT now forces the target bit to output before writing OLAT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
    [Firmware.ino]
2026-10-01 Fix motors
2026-10-06 Prefix pens labels per SVB and add Havna/Sidespor pens
    Physical switch numbers repeat between SVBs (Havna 1-8 vs Fossli 1-7),
    and the tool finds a pens by its label, so labels now carry their SVB:
    F = Fossli, H = Havna, V = Vallekilen.
    - Fossli: F1, F3, F5/6, F7 (Hoyre), F101, F2, F4 (Venstre); SystemConfig.json
    keys renamed to match. EEPROM is slot-indexed and Fossli's slots are
    unchanged, so nothing on the board needs re-uploading.
    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
2026-10-06 Config tool: panel edit menu, resumable panel scans, SCB-first pens picker
    - Config -> 6: edit the SVB panel config without rescanning (swap a panel
    switch's Rett/Avvik, swap two switches, swap dreieskive CW/CCW, reassign
    or remove one LED, swap a pens' Rett/Avvik LEDs, remove an input). Each
    edit sends only the entries it changed.
    - Panel LED and switch scans can be stopped and resumed: keep what's
    configured and scan only the rest; the LED scan offers to store progress
    on Esc. The LED scan now replaces only the scanned board's LEDs instead
    of every panel board's.
    - Pens are picked SCB first, then pens, with hex keys 0-F, so a panel can
    drive LEDs for another SVB's pens (Havna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
2026-10-06 Document drive-vs-feedback rule; drop unused DriveSwitch
    Driving a pens is one bit (Rett or Avvik) and nothing waits for feedback;
    feedback only lights the SVB panel LEDs, which the operator watches. Only
    Motor scan waits, to find which feedback pair belongs to which motor.
    Recorded in .claude/stillverk.chatlog.ned.
    - CommandSession: header comment no longer claims Operate drives via SW.
    - ArduinoDevice: remove DriveSwitch (the SW wrapper), unused since Operate
    flips the motor bit directly. Firmware cmdSW left in place for now.
2026-10-16 Operate Motors: abort on failed slot read instead of using declared pin
    SwitchSlotData.Read returns null when an EEPROM byte fails to read.
    RunMotors treated that as an unscanned slot and fell back to the
    declared motor pin, which can be another switch's motor (F101 -> B1,
    F2's pin). Motor resolution is now ResolveMotors, which returns null on
    a failed read; RunMotors then refuses to drive anything. Addresses the
    PR review comment on CommandSession.cs.
2026-10-16 HWD download: fail on any unreadable row instead of skipping it
    A skipped row left stale registers in hardware.json and an incomplete
    table for Verify EEPROM, while the download still reported success.
    Row parsing moves to ResolvedChip.Parse; the download still reads on to
    END so leftover rows can't leak into the next command. Addresses the PR
    review comment on ArduinoDevice.cs.
2026-10-16 System config download: leave the backup untouched on unreadable records
    Download builds a fresh SystemConfig.json from the board's dump, so a
    record ApplyDownloadLines silently skipped deleted that entry's last
    good backup while still reporting success. ApplyDownloadLines now
    returns the lines it couldn't parse (wrong field count, bad hex,
    unknown record type; OverflowException is now caught too), and Download
    saves nothing if there are any. Records for slots or boards that
    boards.json doesn't know are still ignored on purpose. Addresses the PR
    review comment on SystemConfigSession.cs.
2026-10-16 System config download: count unknown LED roles as unreadable
    A Q record with an unsupported role was skipped silently, so Download
    could replace the backup with an empty LED list. Addresses the PR
    review comment on SystemConfigJson.cs.
2026-10-16 Operate menu: hide sections the board has no hardware for
    Each board menu entry is now shown only when boards.json declares the
    hardware it drives (signals, status LED, track detection, dreieskive,
    motors). Keys stay fixed so a key always means the same section.
2026-11-05 panel leds and switches
